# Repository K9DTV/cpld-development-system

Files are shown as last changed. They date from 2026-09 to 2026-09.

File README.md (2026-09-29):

> **Archived — final / last release.** This project is complete and frozen. Issues and PRs are not expected; the tree is the historical record.
# CPLD Development System

A hand-designed Altera MAX 7000S CPLD development board and the digital labs built on it — from Lake Washington Institute of Technology **Electronics 211** (2017–2018), by **James Burney (K9DTV)**.

This repository packs the PCB design, fabrication outputs, board photos, project write-ups, and a Quartus calculator experiment that targeted the board.

<p align="center">
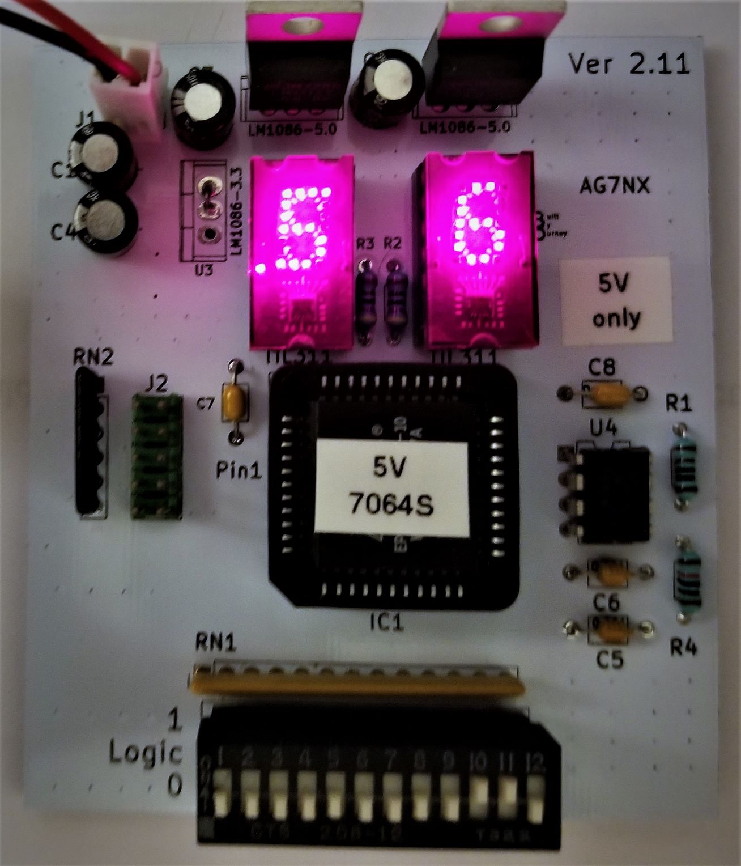
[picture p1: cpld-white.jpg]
CPLD development board (white silkscreen / Ver2)
  
  &nbsp;
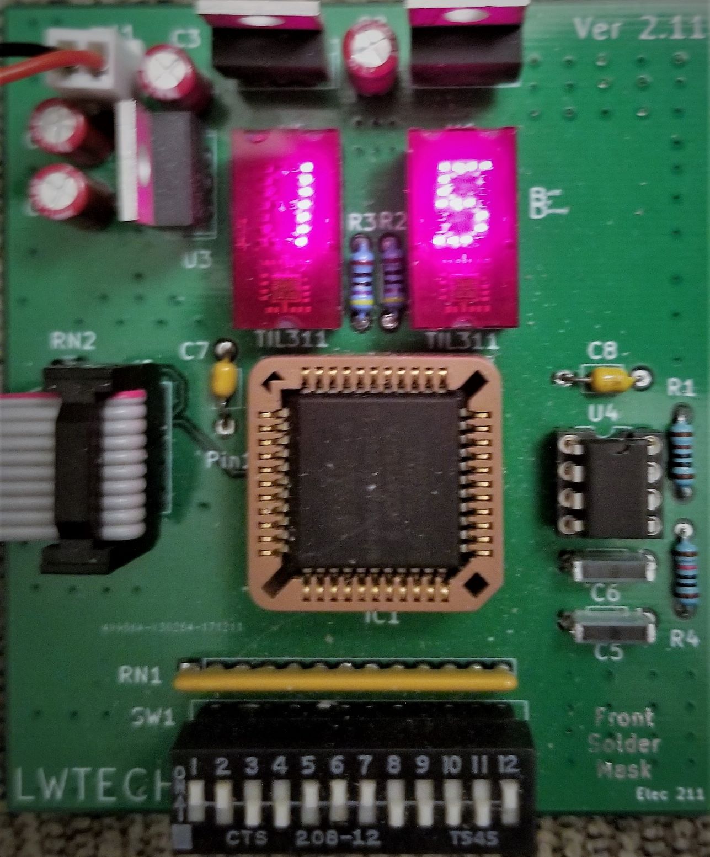
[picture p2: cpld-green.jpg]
CPLD development board (green / Ver1 style)
  
</p>

## What this board is

The goal was a durable **printed** CPLD trainer for the same class work that started on a hand-wired prototype: DIP switches in, dual hexadecimal TIL311-style displays out, on-board clock, and a standard JTAG/ByteBlaster programming header.

Two PCB revisions shipped:

| Version | How to spot it | Notes |
|---|---|---|
| **Ver1** | No silkscreen | Used for most lab examples in the docs |
| **Ver2** | Has silkscreen | Three display-control pins remapped (see pin table below) |

Power: about **6.5 V–12 V** input (prefer the low end; regulators get hot). Current-limit around **160 mA** when using a bench supply. Drive each display **decimal point with an open-drain** buffer so the DP turns fully off.

Supported CPLDs (PLCC-44):

- **EPM7032** (32 macrocells) — enough for display/switch tests  
- **EPM7064AE** (64 macrocells) — needed for the full calculator project  

The Quartus project in this repo is set for family **MAX7000S**, device **EPM7160SLI84-10** (a larger sibling used while compiling the calculator logic).

## Repository layout

```
.
├── README.md
├── cpld-white.jpg / cpld-green.jpg   # Assembled boards
├── cpld-pcb.png / cpld-sch.png       # Layout / schematic views
├── PCB-files/
│   ├── cpld/                         # KiCad schematic + PCB (legacy KiCad 4 era)
│   └── CLPD-grb/                     # Gerbers + drill for fab
├── calulator/                        # Quartus II project (filename spelling preserved)
├── project docs/                     # Word write-ups (board build, PCB, counter, finals)
└── homework/                         # Class notes (ELEC 211 Ch. 4)
```

Folder and filename spellings (`calulator`, `CLPD-grb`, spaces in `project docs`) match the original archive on purpose.

## Hardware pin map

DIP switches are active-low (closed = logic 0). Most designs invert them in the CPLD so “switch ON” reads as a 1 in the logic.

| Function | Ver1 CPLD pin | Ver2 CPLD pin |
|---|---|---|
| DIP SW 1–12 | 4, 5, 6, 8, 9, 12, 11, 14, 16, 17, 19, 18 | same |
| Clock (~66.6 kHz from 555) | 24 | 24 |
| Display A / B / C / D | 27 / 25 / 26 / 28 | same |
| Display Blank | 29 | 29 |
| Right Latch | **31** | **33** |
| Left Latch | **33** | **36** |
| Right DP | 34 | 34 |
| Left DP | **36** | **31** |

Programming-header pins follow the usual Altera JTAG layout (not duplicated in the table).

### Major bill of materials (either revision)

| Ref | Part | Notes |
|-----|---|---|
| IC1 | EPM7032 or EPM7064AE, PLCC-44 | 64 MC for full calculator |
| U1–U2 | LM1117-5.0 | 5 V rails |
| U3 | LM1117-3.3 | CPLD I/O / core as wired |
| U4 | LM555 | ~66.6 kHz board clock |
| U5–U6 | TIL311 (or DIS1417) | Hex displays (hard to source; eBay) |
| SW1 | 12-position DIP slide | Active-low inputs |
| RN1 / RN2 | 10 kΩ SIP arrays | Pull-ups |
| J2 | 2×5 header | Programming |

Full Digi-Key / Mouser part numbers are in `project docs/pcb document and cpld project.docx`.

## Labs and example designs

Documented in `project docs/`:

1. **Board bring-up** — display blank/latch behavior, 555 clock divider blinking both DPs (~1 Hz after ÷65536).  
2. **Priority encoder** — exercises all DIP switches into the hex displays (BCD).  
3. **Calculator** (needs **64 MC** device) — mode select on SW11/SW12:
   - SW11=0, SW12=0 → **min/max** (7485-style compare; DPs show a swap)
   - SW11=0, SW12=1 → **add**
   - SW11=1, SW12=1 → **subtract** (borrow aware)
   - SW11=1, SW12=0 → **multiply**
4. **Two-digit counter** — final-style exercise on the same pinout (`two digit counter cpld project.docx`).
5. **Hand-wired prototype** — earlier 7000-series socket board used for Ch. 4 / Ch. 7 (`211 build board.docx`).

## Quartus project (`calulator/`)

Intel/Altera **Quartus II** project created around March 2018 (Lite / Web edition era). Top entity name: `calulator`.

Block diagrams referenced by the `.qsf` (add/sub, multiplier, min/max, muxes, hex display) originally lived beside the project on the author’s desktop. Those `.bdf` sources are **not** all present in this archive — only the Quartus project shell, `db/`, and `output_files/` reports are. A recent map attempt fails because those schematic sources are missing; treat this folder as historical project metadata unless you restore the BDFs.

Suggested tools: **Quartus II 13.0 SP1** (or the 17.1 Lite build noted in the `.qsf` header) with a USB-Blaster.

## KiCad / fabrication (`PCB-files/`)

- `PCB-files/cpld/` — schematic (`.sch`), board (`.kicad_pcb`), netlist, project (KiCad 4-style `.pro`).  
- `PCB-files/CLPD-grb/` — Gerber layers (F/B Cu, mask, silk, edge cuts) and `cpld.drl`.

Open with a modern KiCad via the legacy importer, or send the Gerbers straight to a fab.

<p align="center">
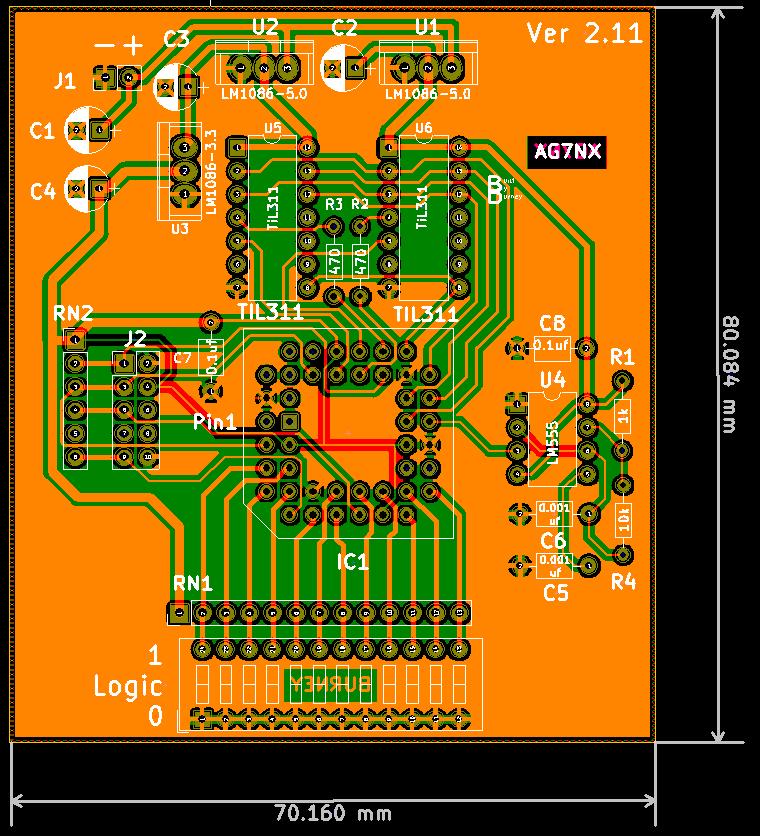
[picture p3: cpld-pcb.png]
PCB copper / X-ray style view
  
  &nbsp;
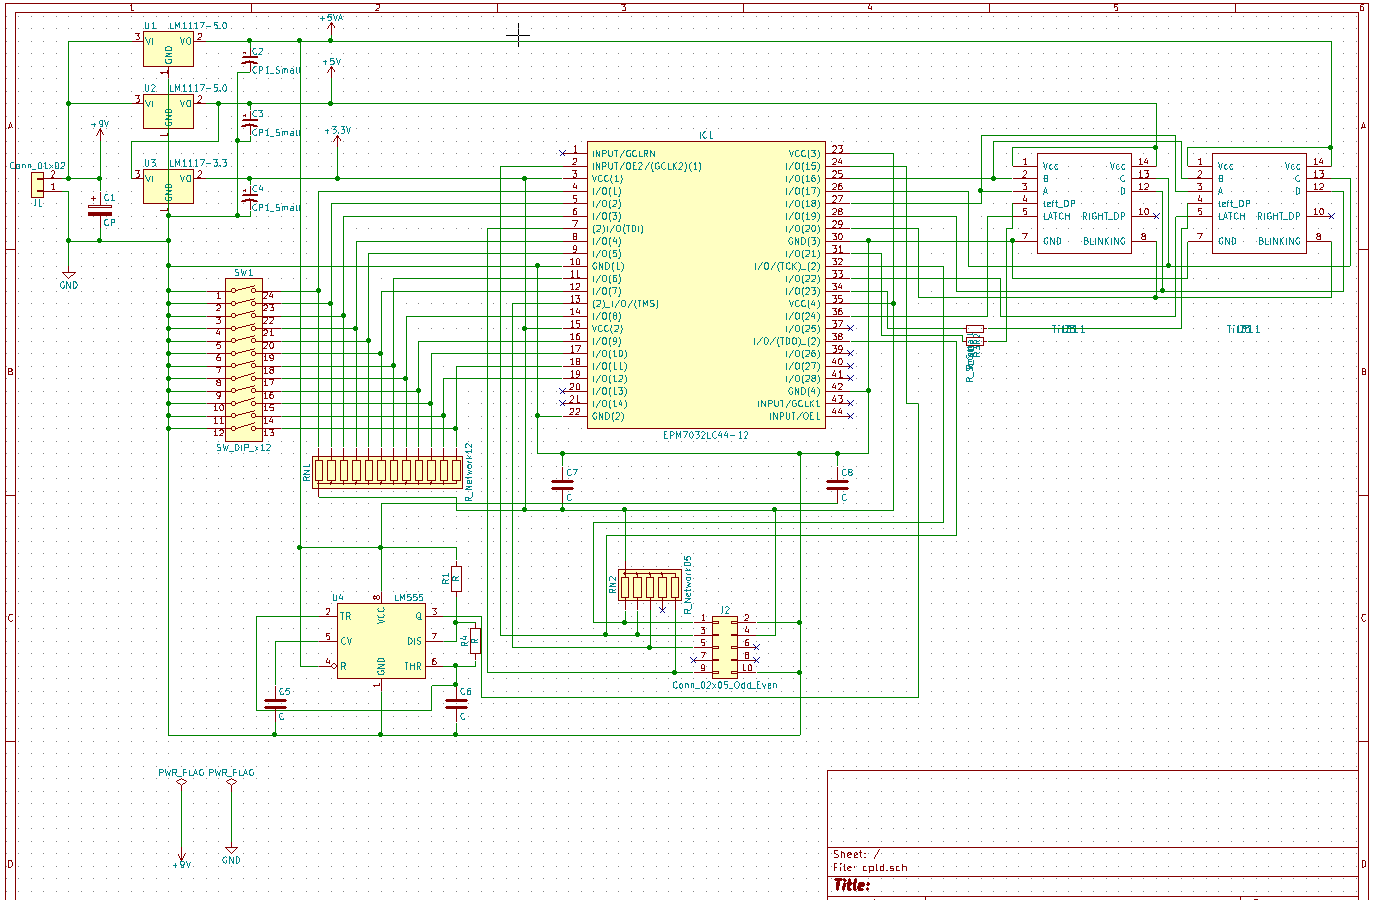
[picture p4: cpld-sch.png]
Board schematic excerpt
  
</p>

## Documentation (`project docs/`)

| File | Contents |
|---|---|
| `211 build board.docx` | Hand-wired prototype + Ch. 7 calculator path |
| `pcb document and cpld project.docx` | Ver1/Ver2 PCB, pin map, BOM, calculator labs |
| `two digit counter cpld project.docx` | Counter lab on the PCB |
| `211 PROJECT.docx` / `211 final.docx` | Course project / final write-ups |

Course context: **Lake Washington Institute of Technology**, Electronics 211, instructor **Professor Peter Welty**.

## License / provenance

MIT -- see [LICENSE](LICENSE). Personal educational hardware and reports by James Burney (K9DTV). Course homework notes in `homework/` are included as archived class material. Altera/Intel tool output remains under their respective license terms.

Site / contact: [k9dtv.com](https://k9dtv.com) · GitHub: [K9DTV](https://github.com/K9DTV)

---

*Archived from the original CPLD development-system materials (2017–2018) and published as a public K9DTV project.*

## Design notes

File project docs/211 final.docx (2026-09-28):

Lake Washington Institute of Technology

Electronics 211

Final

Priority encoder / Full Adder / Subtraction

Feb 20^t^h, 2017

James Burney

Electronics 211, Final – James Burney, Feb 20^t^h, 2017

Executive Summary – The goal the final was to use the development board that was made for chap7, and make a calculator that was a full-adder, it needed to be able to add two hexadecimal numbers. In this report, I will discuss everything I did done with this board and how I did them, and what was learned. So, in the end, the goals of the final was completed by following the fine directions of our instructor, Professor Peter Welty.

Parts used

7000ae CPLD

FDN 367 display

44 Pin PLCC Socket

10 10KOhm ¼W 5%

8 270 Ohm ¼W 5%

10 pos sw.

LM 1117 3.3

32Ga wire

Equipment used

HP 34401a

Windows 10 pc with usb blaster

I first had to use the schematic of what was done with the pin assignment of the 7000 CPLD. This was used in the end programming of the CPLD to match my assignments.

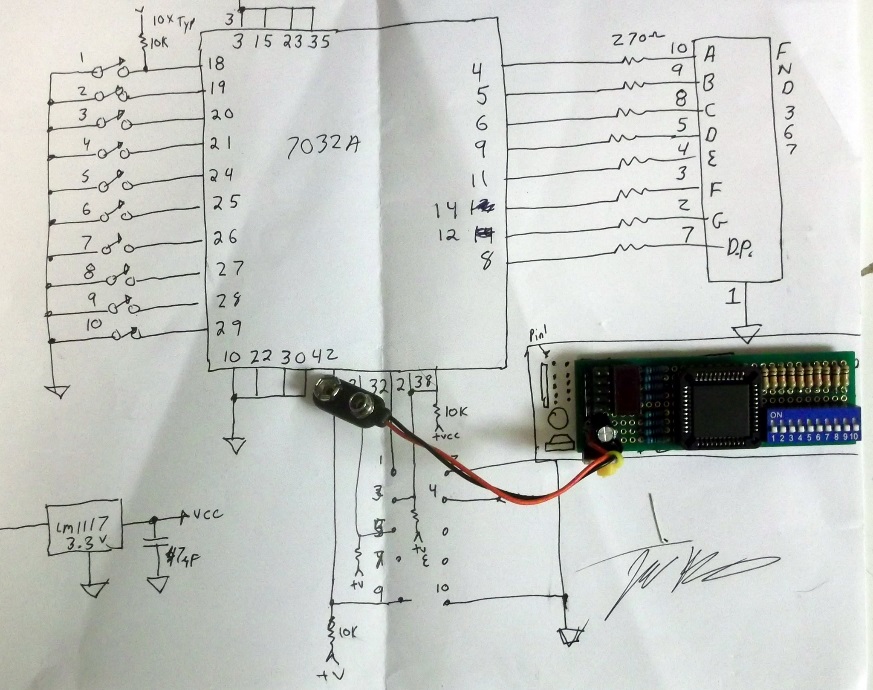
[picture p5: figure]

Electronics 211, Final – James Burney, Feb 20^t^h, 2017

After building the board, I wanted a simple way to test that all of the I/O of my layout, and test all parts of the board. To this end, I used a priority encoder to read the switch inputs from 1 to 9 and feed them into a 74147, the output was feed into a 7447 to convent the BCD to 7 segment display. The 10th switch was feed to the displays D.P. to show it operation. Some mods were made to the 74147 for negative logic levels in my design, this will be discussed later in the report.

Priority Encoder (10 to 4 Encoder) BCD Display Driver

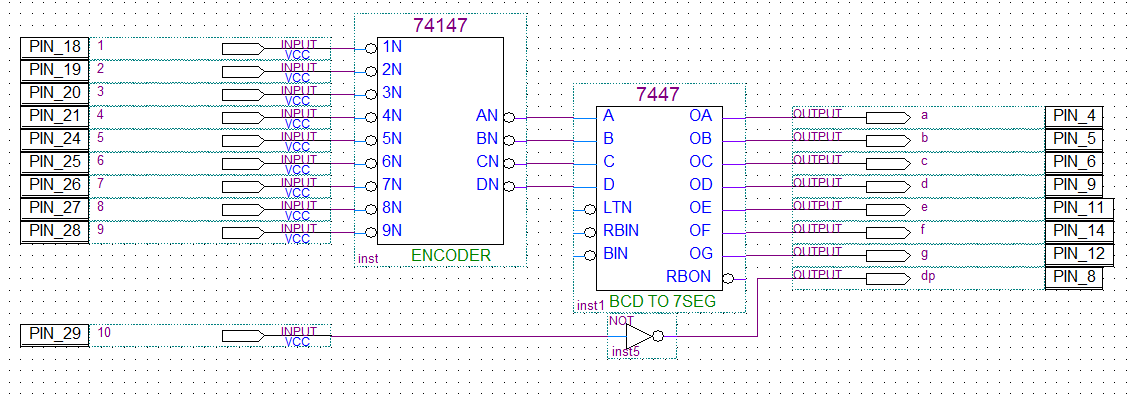
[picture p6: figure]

Next part of this lab was to build a Full adder with carry and a Hex to 7 segment display driver. This adder seemed straight forward, however, I was unable to find a hex display driver in the Max catalog of parts.

I decided to make my own and thought about it and came up with three ways to do it, mod a 7447, use a LUT, or, make a decoder and encoder, I chose the latter. First, I stared with a 4 to 16 decoder, or in other words a Binary to decimal converter. Knowing that I only had four inputs in, I knew I could use the invert and non-inverted inputs to drive 4 input gates and decode any binary number from 0x0 to 0xF. I setup 8 columns made of 1248 and not 1248, this feed 16 quad AND gates. Each gate hooked to the right code for the corresponding output. My inputs to this part of the decoder is negative logic as a switch closure is low for an on state. If one wanted to convert to positive logic, all that’s needs to be done is add four inverters in-line with the ABCD inputs. AND gates were used to decode the negative logic to convert it to decimal.

Next step was to encode this decimal number to a 7-segment display, again I thought about this and decided

It would be best to apply negative logic here to simplify the encoding. The reasoning here is that the number with the most segments on is the number eight with all 7 segments on, followed by 6 with 6 segments on. If I use negative logic, no gates will be used to decode 8, this leaves a maximum gate size needed at 6 inputs, furthermore, I only have to wire the segments to the gates that I want to be off, hence, negative logic.

Again, I setup 15 columns, as number 8 was not needed, I laid down (7) 6-input NOR gate (change to OR for CA display), one gate for each segment of the display. I simply wired each output from the decoder to each segment gate that I did not want on, this made the right numbers show up for the decode.

Next I changed out the 6-input gates that did not use all their inputs with 4-input gates. Then I did some cleanup in wiring and compression of the layout.

Next came testing and debug, and I did make some wiring mistakes, but with some troubleshooting done in the real world, I was able to solve these errors in short order.

Electronics 211, Final – James Burney, Feb 20^t^h, 2017

Binary to 7-egment display driver

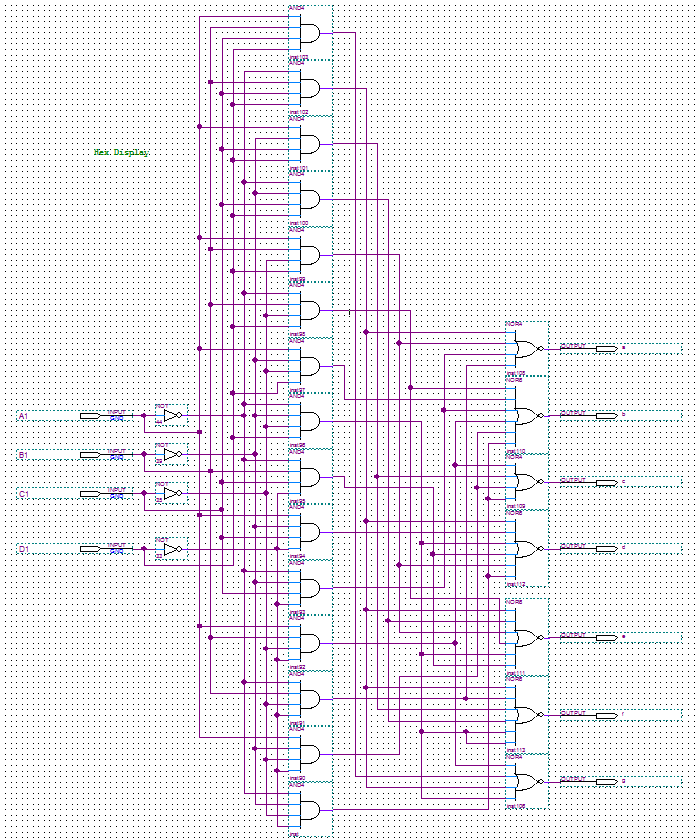
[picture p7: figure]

Although this may look hard, it is fairly straight forward and much easier to do, than to do on a breadboard.

I learned a lot from this, I learned to really think about the way I was using the gates, as resources are limited in this chip, and one wants the most bang for the buck here. I learned how to really use hierarchical deigns to simplify the work flow.

Electronics 211, Final – James Burney, Feb 20^t^h, 2017

Next up, add the full-adder, this was very easy and straightforward. I just dropped in a 7483 and bob's your uncle. So, getting no real joy from this I moved on to the extra credit stuff.

Full-Adder with carry

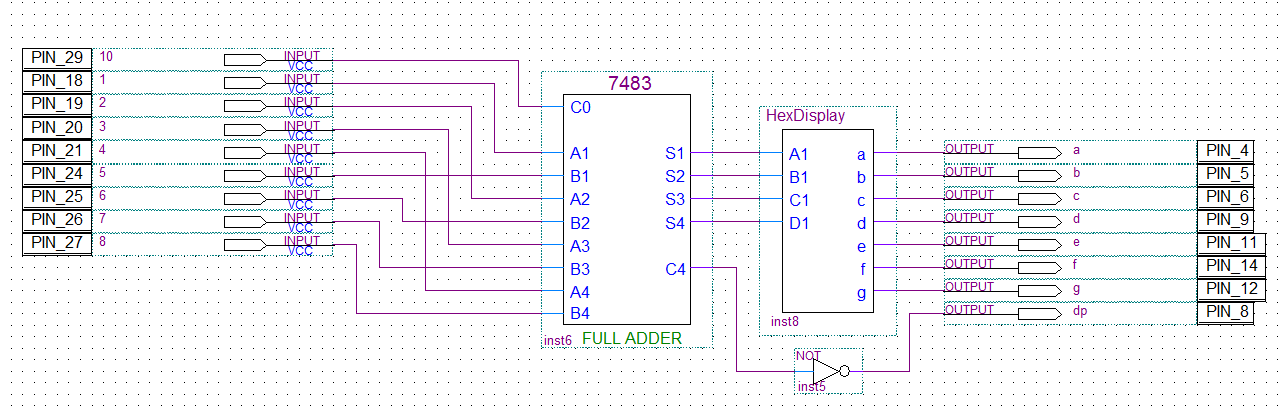
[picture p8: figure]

Next up, Full-adder with carry and subtraction with added logic for correcting DP. To add subtraction to the full-adder, all that is needed is to do a 2’s complement on the second half of the binary inputs and set the input carry to the 7483. To make it add/subtract selectable, XOR’s were used. Some added logic was also used to suppress the DP in subtraction mode.

Add/Subtract switching and DP suppression

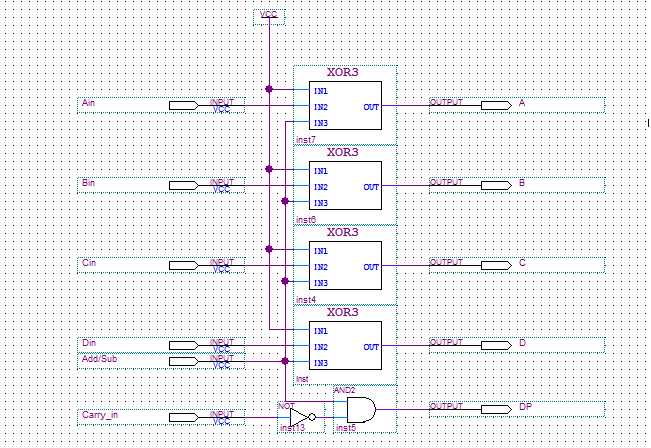
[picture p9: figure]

Full-Adder with carry / Subtraction. With D.P. suppression

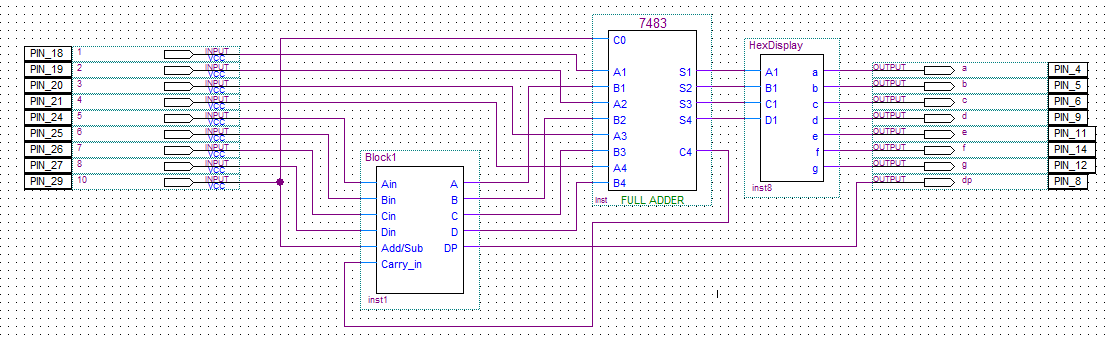
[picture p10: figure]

Electronics 211, Final – James Burney, Feb 20^t^h, 2017

Having completed the extra credit part, I still wanted to go on, so I decided that combining all this into one design, to see if I could use most of the chip, this would be great. To do this, I had to add multiplexing to the design, for inputs to the priority encoder and the adder/sub mod, and for the display.

First, I multiplexed the display converter, as seen below. This was easy as there is already a chip to do this.

All I had to do is a little layout.

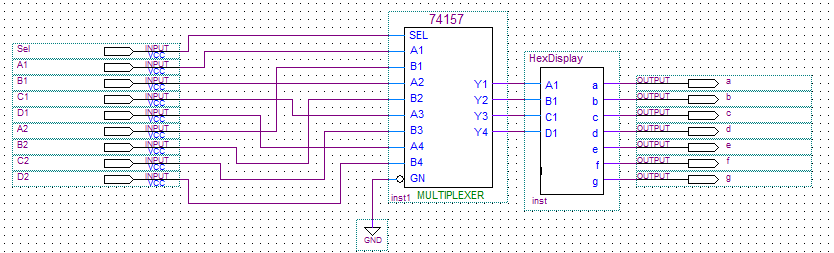
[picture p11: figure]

Next, it did come combining of the add/sub mod, as seen below. This was another easy step as I had already designed the subtraction unit with DP suppression.

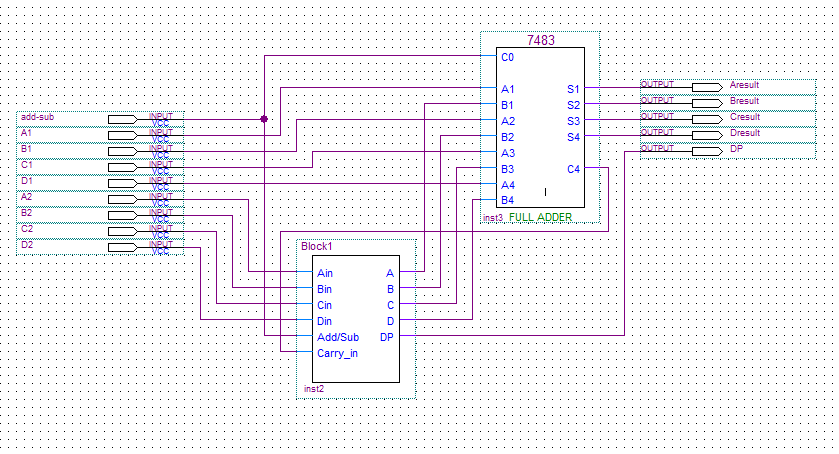
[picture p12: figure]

Electronics 211, Final – James Burney, Feb 20^t^h, 2017

Next up was to make a large 1 to 2 selector with 9 inputs and 18 outputs. This was all about layout to make the job easy. I laid out columns as before, and went ahead with wiring gates to the inputs and outputs.

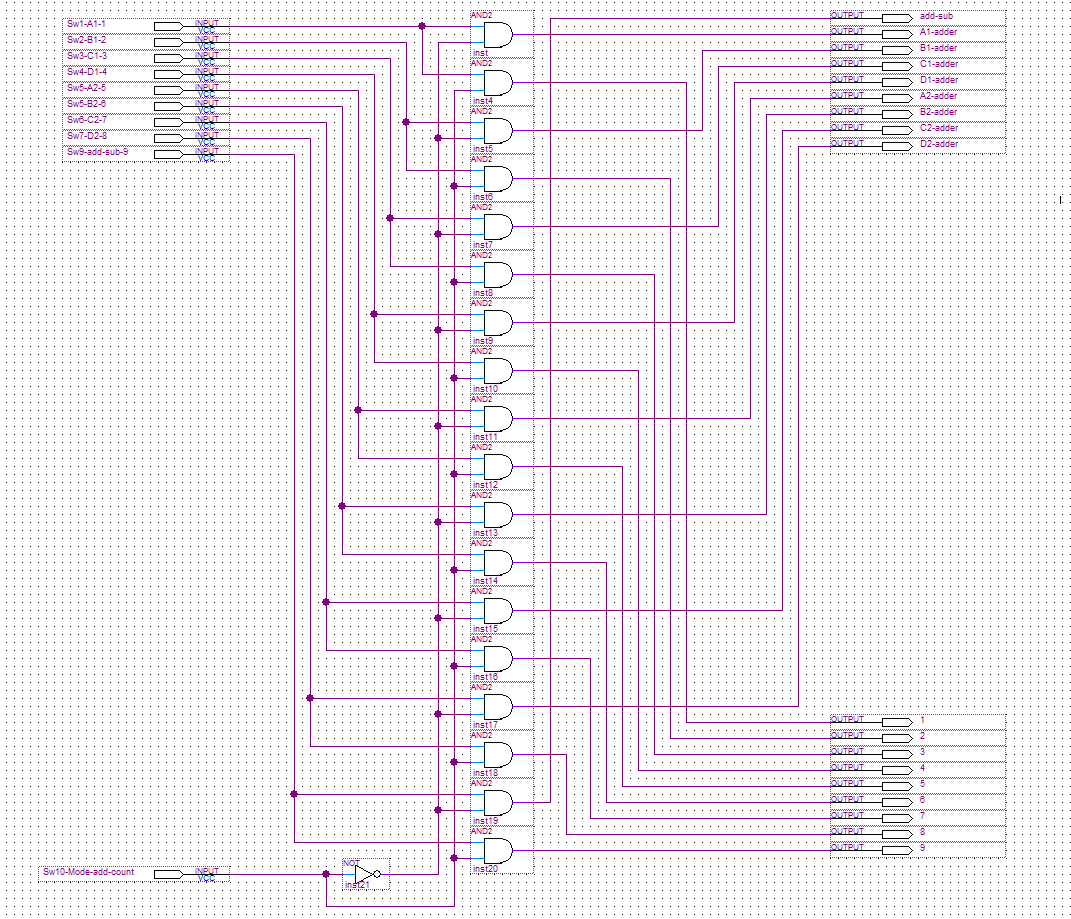
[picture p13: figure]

Next, I took all these combined sections and wired them up, as seen below.

Some changes were needed to the priority encoders first layout, as switch 10 could no longer be used just for the DP on the display, as this become the mode select switch. Switch 10 selects priority encoder when switch 10 is in the off position, and selects the adder/sub when it is on. When switch 10 is on, switch 9 becomes the add/sub selector switch, with off being add, and on being subtract.

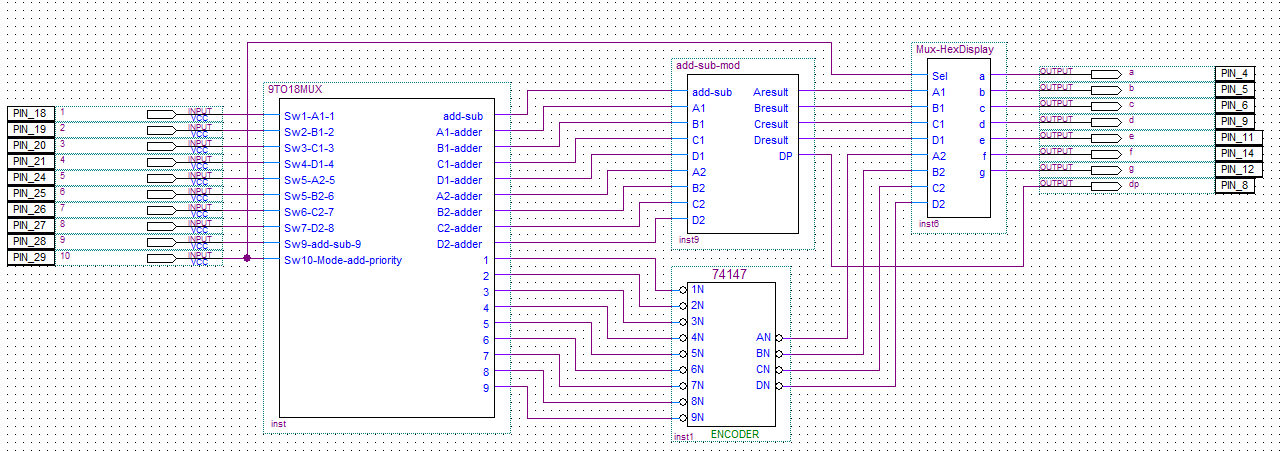
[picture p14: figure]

Electronics 211, Final – James Burney, Feb 20^t^h, 2017

Adding the priority encoder to the full adder with carry and the subtraction selector with suppression.

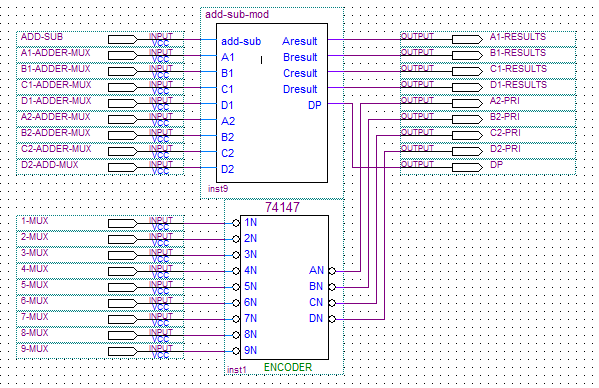
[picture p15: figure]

More hierarchical deign, however, labeling seems to take over the design.

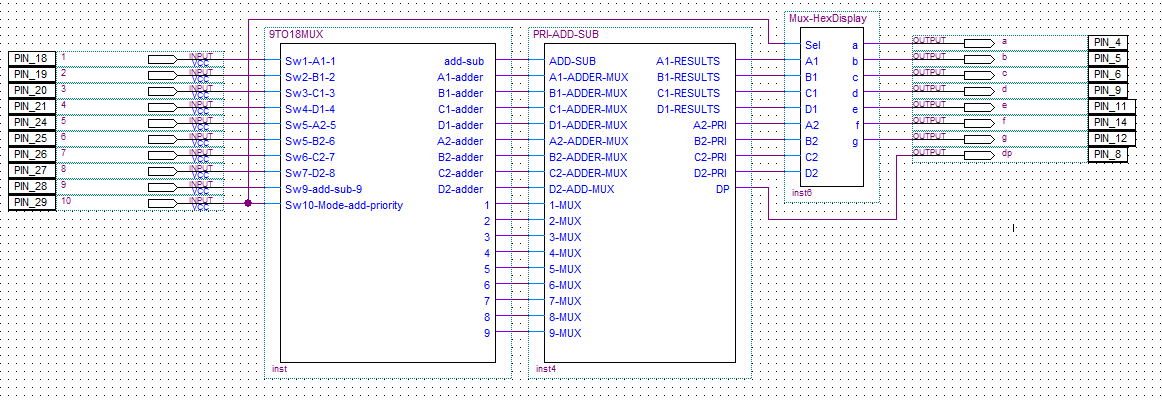
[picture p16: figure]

Next up, the ultimate reduction of this hierarchical deign, just a little too much I think.

Did not make it to my goal of 100% usage, but did make 75%

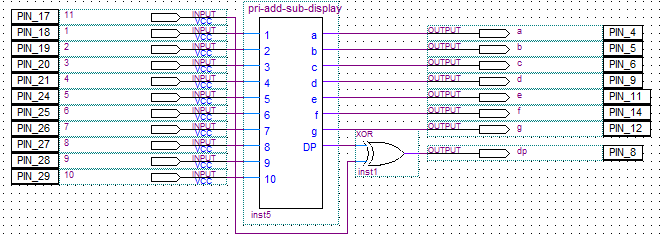
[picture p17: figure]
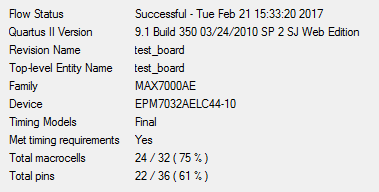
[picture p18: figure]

Electronics 211, Final – James Burney, Feb 20^t^h, 2017

Photographic documentation

Priority encoder one only

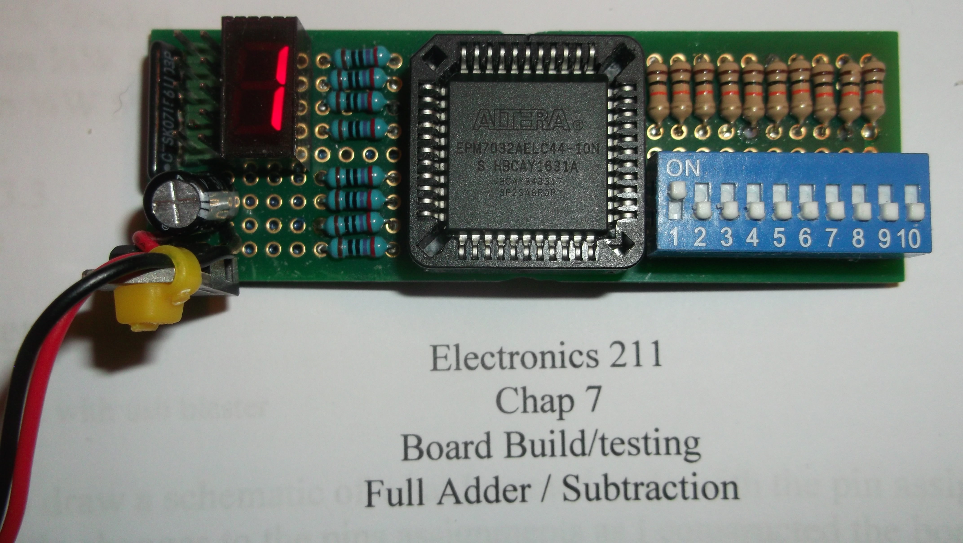
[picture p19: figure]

Priority encoder nine only

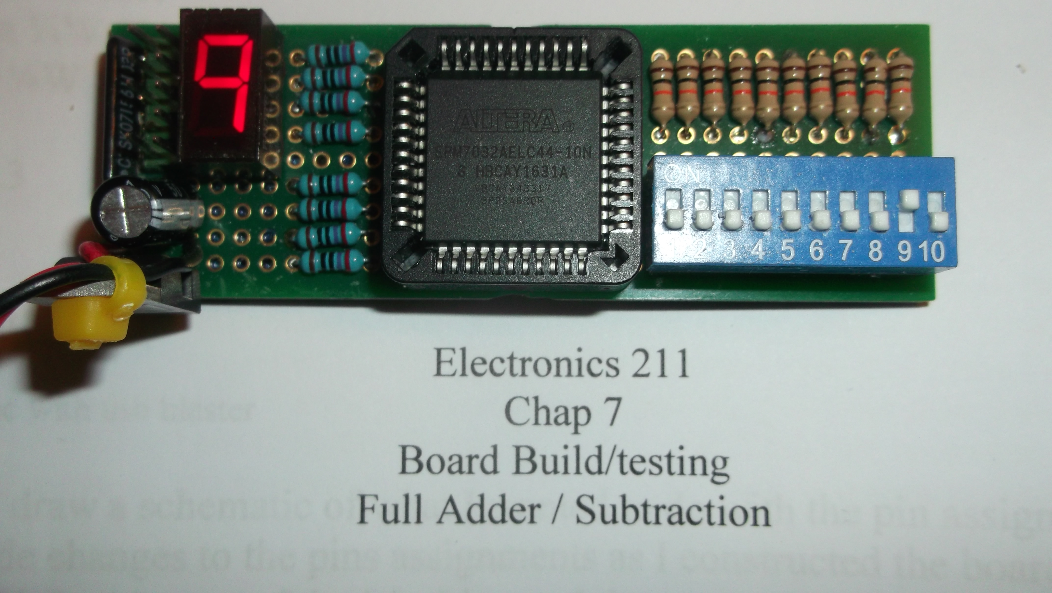
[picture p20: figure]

Priority encoder nine & 1 to 5

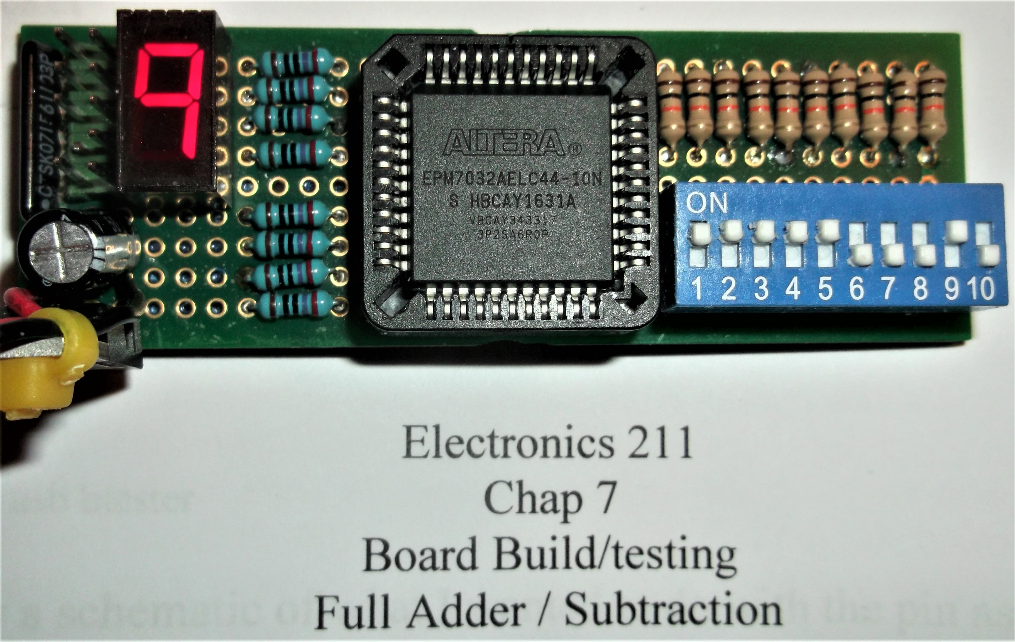
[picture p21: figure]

Electronics 211, Final – James Burney, Feb 20^t^h, 2017

Full adder with carry

0x8 + 0x2 = A or 8+2=10

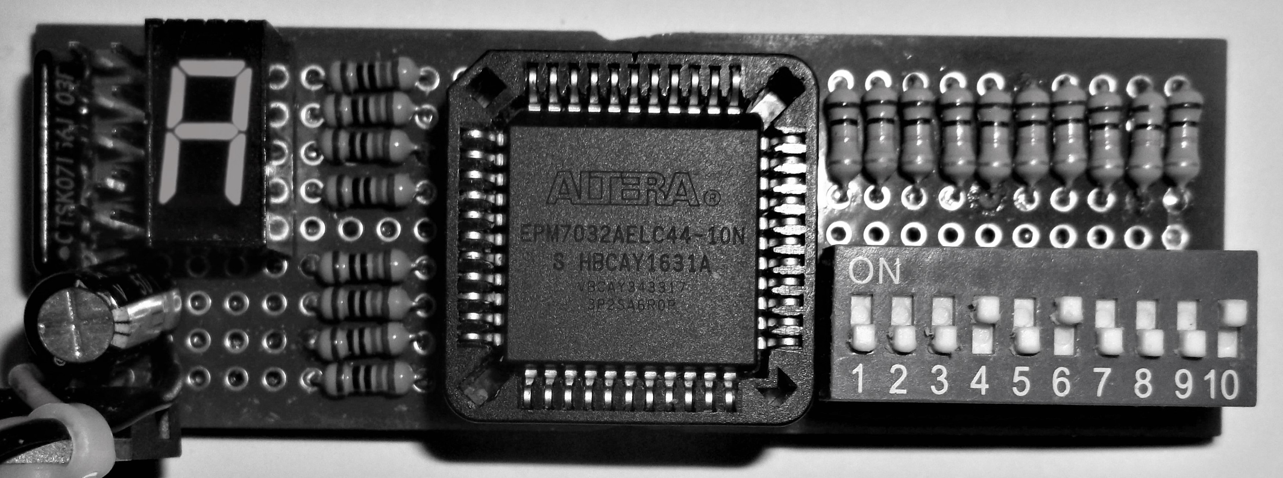
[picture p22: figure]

0x7 + 0xF = 0x16 or 7+15=22

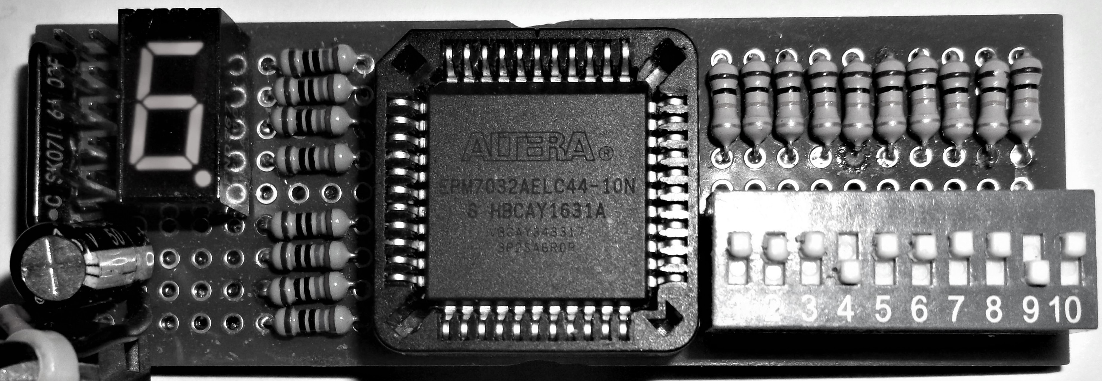
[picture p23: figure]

Subtraction

0x7 – 0x4 = 0x3 or 7-4=3

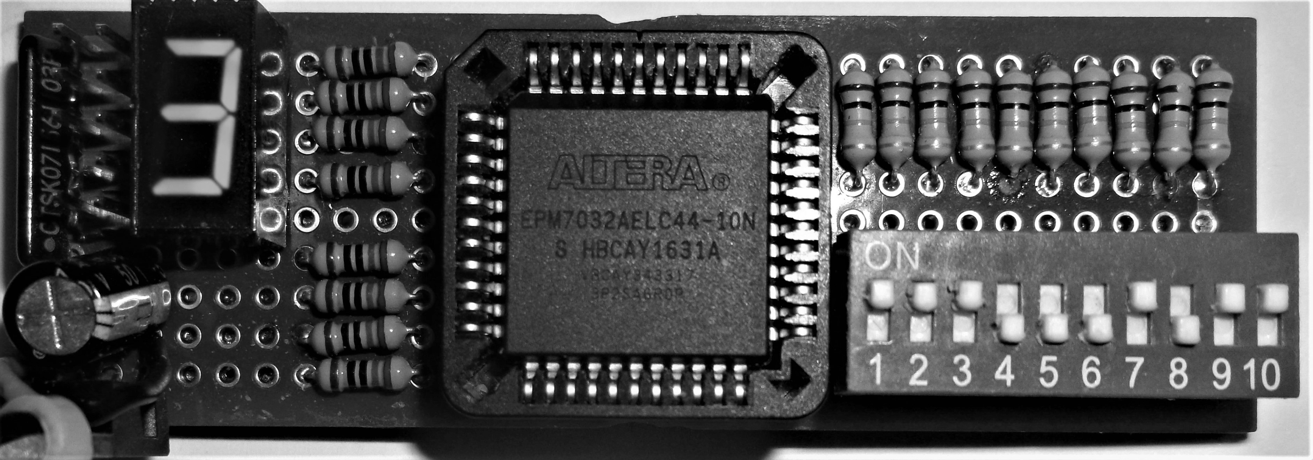
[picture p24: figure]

0x3 – 0x8 = B

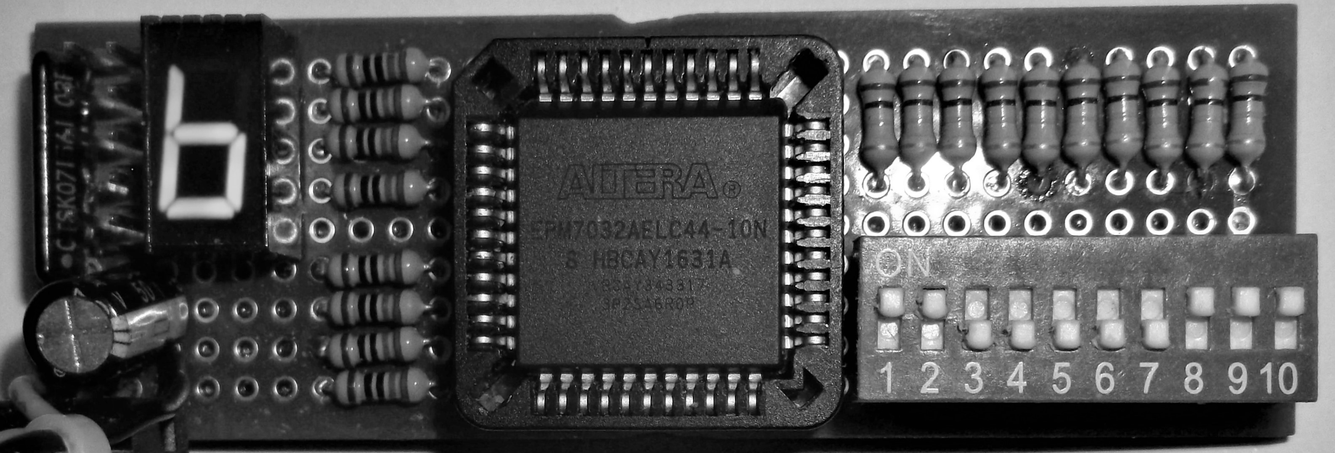
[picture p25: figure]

Electronics 211, Final – James Burney, Feb 20^t^h, 2017

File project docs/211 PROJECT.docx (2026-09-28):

Lake Washington Institute of Technology

Project CLPD Calculator

Feb 22^t^h, 2017

James Burney

Calculator Project – James Burney, Feb 22^t^h, 2017

Executive Summary – The goal the project was to use the development board to really build the calculator from the chapter 7 of the elec 211 book. First a lager chip needed to be ordered, as the design would not fit on a 32-cell unit, so a 64-cell chip was used.

Then there are some problems with the design presented in the book, along with some short cuts taken that do not take advantage of the fact a CLPD is being used in the first place.

In this report, all the steps to make this calculator will be covered mainly from a Negative logic point of view, as this is what most building this will use. Also, covered will be displaying results, and borrowing when subtracting.

Parts used

EPM7064AELC44-10 CLPD

FDN 367 display

44 Pin PLCC Socket

16 10KOhm ¼W 5%

8 270 Ohm ¼W 5%

12 position switch.

LM 1117 3.3v

32Ga. wire

First off, lets cover that this design is based on negative logic, as the input switches when on, zero volts is used to represent a logical 1, and to turn an LED on, zero volts is used to represents a logical 1. The book uses positive logic and in most cases it is a simple matter of just inverting the inputs, and the output, but not in all cases.


Calculator Project – James Burney, Feb 22th, 2017

Now to take a look at a schematic of the development board, this is not a complete schematic, as one will make their own choices as they build their unit.

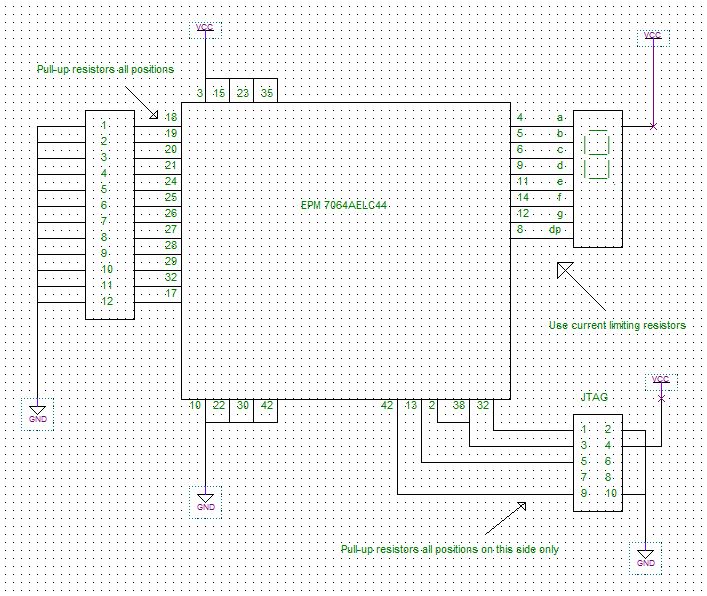
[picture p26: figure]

It should be noted imminently, that current limiting resistors, and pull-up resistors are not shown, but are needed. A minimum of a 11-position switch, and at least one 7-segment display is needed.

Note here that all parts are from a bottom view, and the regulator is a LM1117 3,3v type. Be sure to make sure the regulator you use is the same pinout.

Calculator Project – James Burney, Feb 22th, 2017

It is not the intent of this project to help you build your board, but help you in making the calculator in chapter 7 of the lab book, along with some improvements in layout and design.

The book starts out with an adder, then a full-adder and the adds subtraction to it. The book really did not cover a display driver, as it wanted you to use an extremal display decoder for this task, and that kind of defeats the whole reason for using the CLPD in the first place. So, I’ll start off with a display decoder, and if you don’t need to use a Hexadecimal display, just use a 7447 from the library of parts

For building the hex display, First, I stared with a 4 to 16 decoder, or in other words a Binary to decimal converter. Knowing that I only had four inputs in to decode the 16 states, I knew I could use the invert and non-inverted inputs to drive 4 input gates and decode any binary number from 0x0 to 0xF. I setup 8 columns made of 1248 and NOT 1248, this feed 16 quad AND gates. Each gate hooked to the right code for the corresponding output.

My inputs to this part of the decoder re negative logic, as a switch closure is low for an on state. If one wanted to convert to positive logic, all that’s needs to be done is add four inverters in-line with the ABCD inputs. AND gates were used to decode the negative logic to convert it to decimal.

Next step was to encode this decimal number to a 7-segment display, again I thought about this and decided

It would be best to apply negative logic here to simplify the encoding. The reasoning here is that the number with the most segments on is the number eight with all 7 segments on, followed by 6 with 6 segments on.

If I use negative logic, no gates will be used to decode 8, this leaves a maximum gate size needed at 6 inputs, furthermore, I only have to wire the segments to the gates that I want to be off, hence, negative logic.

Again, I setup 15 columns, as number 8 was not needed, I laid down (7) 6-input NOR gate (change to OR for CA display), one gate for each segment of the display. I simply wired each output from the decoder to each segment gate that I did not want on, this made the right numbers show up for the decode.

Next I changed out the 6-input gates that did not use all their inputs with 4-input gates. Then I did some cleanup in wiring and compression of the layout.

Next came testing and debug, and I did make some wiring mistakes, but with some troubleshooting done in the real world, I was able to solve these errors in short order.

Note that if you are using positive logic or a common cathode display, just add four inverters to the inputs.

If you are using both positive logic and a common cathode display, invert both inputs and outputs,

The best way to invert the outputs is too change out the NOR gates with OR gates.

Calculator Project – James Burney, Feb 22th, 2017

Binary to 7-egment display driver


Although this may look hard, it is fairly straight forward and much easier to do, than to do on a breadboard.

I learned a lot from this, I learned to really think about the way I was using the gates, as resources are limited in this chip, and one wants the most bang for the buck here. I learned how to really use hierarchical deigns to simplify the work flow.

Calculator Project – James Burney, Feb 22th, 2017

I am going to skip the adder/full-adder, and just jump in to the adder with carry and the subtraction.

The Full-adder with carry and subtraction with added logic for correcting DP. To add subtraction to the full-adder, all that is needed is to do a 2’s complement on the second half of the binary inputs and set the input carry to the 7483. To make it add/subtract selectable, XOR’s were used. Some added logic was also used to suppress the DP in subtraction mode. Again, this is for negative logic.

Add/Subtract switching and DP suppression


I used the logic below to test my ideas based on the information provided by the book. Then added to it to even add a borrowing to it when subtracting.

Full-Adder with carry / Subtraction. With D.P. suppression


Calculator Project – James Burney, Feb 22th, 2017

After getting my full adder with carry, and subtraction with borrow working, this is what it now looks like.

DE Morgan theorem was used here to figure out how to drive the display for adding and subtracting with carry and borrowing.

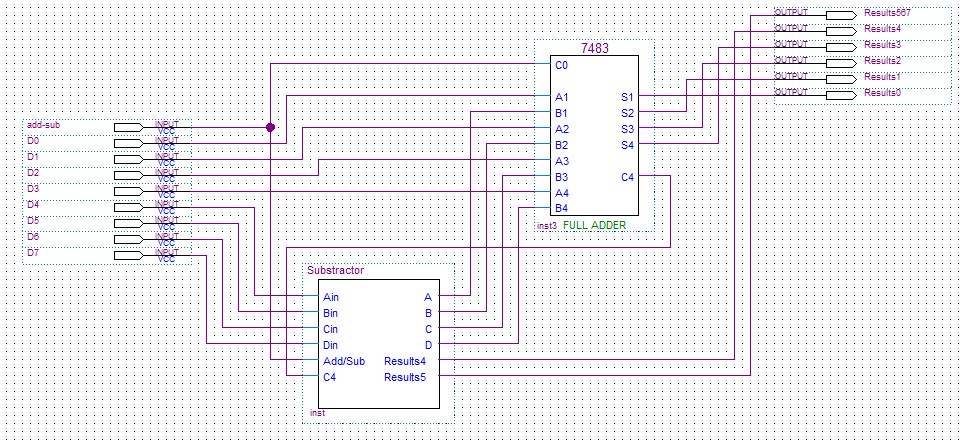
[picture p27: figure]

Here are the details of the subtraction unit with borrowing. This allows only four states on the MSD of the display. The four allowed states are F, E, 1, and 0. F and E are used in subtraction and 1, and 0 are used in addition with carry.

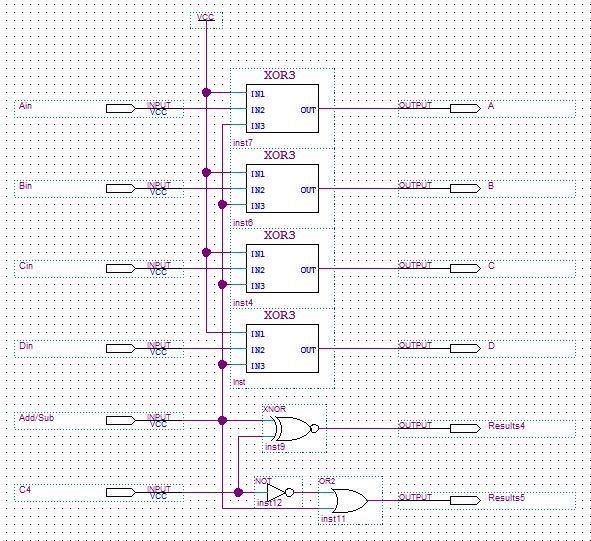
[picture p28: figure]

Calculator Project – James Burney, Feb 22th, 2017

Now would be a good time to look at the multiplier, the book does a good job of showing you the multiplier, however, really does not do a good job on its layout. Also, it was designed for positive logic.


However, as said earlier, it is easy to convert in most cases. In this case, the easiest way to do this conversion, is to simply remove the inverts on the inputs and the outputs. Care must be taken when doing this as layout as it is a little complicated.


Next in Min-Max, this is just a magnitude comparator driving two 2 to 1 multiplexers. The state of AGBO and ALBO determines what nibble will be displayed on digit. To convert to positive logic, just simply remove the inverts on the inputs and the outputs, and reverse the AGBO, and ALBO connections.

Calculator Project – James Burney, Feb 22th, 2017

Next the book made a multiplexer for the three-function calculator by using three tristate buffers.

This however is a problem, as the book did not use a display encoder internally, they could use these buffers on the output of the device. However, tristate buffers are not allowed on the internal buss of the EPM70xxA, a real multiplexer must be used. Now to do this, you could just use a 74157, but I wanted to conserve space in the CLPD, so I made my own.

The multiplexer has to select one of the three functions of the calculator. As can be seen, the decoder logic is just inverting the control signals.


Calculator Project – James Burney, Feb 22th, 2017

Now multiplexing the display, as I only used one 7-segment display, and this calculator needs two digits. This CLPD has more than enough pins to add a second display. Only 23 pins were used and this leaves 13 pins for you to add another display and even more input switches.

If you chose to add a second display, only 5 microcells are left, however, deleting the display multiplexer should make this fit. (Tried it and it will not fit)

The multiplexed the display converter, as seen below.

Next, I took all these combined sections and wired them up, as seen below.

This is where careful layout of the hierarchical deign comes in. this makes understanding the follow easy.

I really don’t think the book conveyed this very well.


The final design showing the pinout used in this design.


Calculator Project – James Burney, Feb 22th, 2017

Usage of the EPM7064AE

Photographic documentation

Note: The decimal point of the display shows what digit is being displayed. With the decimal point lit, the MSD is displayed and off is the LSD.

Full adder with carry (switch 9 is add/subtract. add is the off position)

0x1 + 0x0 = 1


0x1 + 0x8 = 9


0x9 + 0x9 = 0x12


It is easy to see in the pictures above, that the carry function works just fine.

Calculator Project – James Burney, Feb 22th, 2017

Subtraction with borrow

0x3 – 0x1 = 02 (switch 9 is add/subtract. Subtract is the on position)


0x1 – 0x9 = 0xF8


Greater than / Less than

0x3 > 0x1 = 0x31


0x2 < 0x4 0x42


Calculator Project – James Burney, Feb 22th, 2017

Multiplication

0x6 X 0x2 = 0x0C


0x7 X 0xA = 0x46


0xF X 0xF = E1


Calculator Project – James Burney, Feb 22th, 2017

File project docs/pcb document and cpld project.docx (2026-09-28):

Lake Washington Institute of Technology

7th Quarter Project

CPLD development board

January 12, 2018

Jim Burney

7th Quarter Project - CPLD development board CPLD - Jim Burney – January, 2018

Executive Summary – The goal of this project was to make a very high quality Printed Circuit board for making things like the calculator from the Digital Electronics Class 211. Using

This project documents the two revisions of the boards made, and some examples what can be done with them. This project took over 33 hours for the development of the documentation, and the development of the projects to make with it. What follows is the documentation of the two versions. Even though the two only have three pins from the CPLD to the display changed, this needs to be shown.


Ver1


Ver2

7th Quarter Project - CPLD development board CPLD - Jim Burney – January, 2018

The easiest way to tell the two versions apart is simple, version 1 has no silkscreen, and version 2 does. There are also other minor changes in the layout, to make the board better.

What follows is the pin assignments used for the two boards, this is really all that matters for their use.

Component Version1 Version2

CPLD Pin CPLD Pin

Dip switch 1 4 4

Dip switch 2 5 5

Dip switch 3 6 6

Dip switch 4 8 8

Dip switch 5 9 9

Dip switch 6 12 12

Dip switch 7 11 11

Dip switch 8 14 14

Dip switch 9 16 16

Dip switch 10 17 17

Dip switch 11 19 19

Dip switch 12 18 18

Clock 66.6KHz 24 24

Display

Right/left A 27 27

Right/left B 25 25

Right/left C 26 26

Right/left D 28 28

Right/left Blank 29 29

Right Latch 31 33 *

Left Latch 33 36 *

Right DP 34 34

Left DP 36 31 *

*Changes made from version 1 to version 2

Ver1 is used for all examples used in this report.

Note: The pins to the programming header are not shown as they are standard.

some notes on the use of this board, always drive the Decimal Point of the display with and Open Drain buffer. If you don’t, the DP may not turn fully off completely, depending on the voltage supplied. The supply voltage should be from 6.5 Volts to 12 Volts, and current should be limited to about 160mA. Iif using a power supply, please current limit. The regulators will get very HOT, so it is better to operate on the lowest voltage possible. At 9V input, power dissipation is 3/4Watts in the 5V regulators.

7th Quarter Project – CPLD development board CPLD – Jim Burney – January, 2018

The following is the parts list for either version of this board.

R1 1K ¼ WATT 1% RNF14FTD1K00CT-ND

R2-R3 470 Ohms ¼ WATT 1% RNF14FTD470RCT-ND

R4 10k ¼ WATT 1% RNF14FTD10K0CT-ND

RN1 ARRAY 12 RES 10K 13Sip 4613X-101-103LF-ND

RN2 ARRAY 5 RES 10K 6Sip CSC10KE-ND

C1-C4 22uF 16v 710-860020372002 Mouser

C5-C6 1000pF 495-6839-ND

C7-C8 .1uF 478-5194-ND

IC1 CPLD 32MC 10NS PLCC 544-1995-ND

*Or CPLD 64MC 10NS PLCC 989-EPM7064AELC44-10 Mouser

U1-U2 LM1117-5.0 LM1117T-5.0/NOPB-ND

U3 LM1117-3.3 (https://www.digikey.com/product-detail/en/texas-instruments/LM1117T-5.0-NOPB/LM1117T-5.0-NOPB-ND/363594)LM1117T-3.3/NOPB-ND

U4 LM555 LM555CNFS-ND

U5-U6 Til311 HARD TO FIND (See note) eBay / Jim Burney

SW1 SLIDE DIP 12-POS CT20812-ND

J1 1x2 Header 2.54mm WM18785-ND

J2 2x5 Header 2.54mm 437-8021001010002101 Mouser

PCB Custom Board JHB00005 Jim Burney

Sockets for board

PLCC44 AE10057-ND

**DIP-24 Pin 575-1104732441001000 Mouser

**DIP-14 Pin (2 needed) 575-1104731441001000 Mouser

**DIP-8 Pin 575-1104730841001000 Mouser

**Adhesive feet (4 needed) RM822-ND

*needed if you want to do all projects

**Optional parts.

All parts are from Digi-key unless otherwise noted.

NOTE: The Til311 can be found on eBay also, the DIS1417 may be able to replace the Til311.

By the time you are done, the cost will be about $100 for each assembled board, if done in quantity of ten. Your mileage may vary, as mine was much higher, as three different boards were made and each set of 10 cost about $40.

7th Quarter Project – CPLD development board CPLD – Jim Burney – January, 2018

Ver1


Ver2


Note: Pin 1of RN1 is on the right side for version 1, and on the left side for version 2.

7th Quarter Project – CPLD development board CPLD – Jim Burney – January, 2018

The first project was done to test the displays, and the clock on the board, this is really a simple test. Switch 1 is the A bit, and 2 is B, 3 is C, and 4 is D. Switch 9 is the Latch to the Left display, and 10 is Latch to the right display. Finally switch 12 controls the blanking of the displays.

Negative logic comes from the switches, as they provide a low (0) when the switch is on, so all switches used are inverted, so that when the switch is on, it makes this a high (1).

Ver1 is used for all examples used in this report.

This takes the negative logic from the switches and converts it to positive logic for the display.

By doing this, it makes it easier to understand how the hexadecimal displays work.

First you can see that as long as switch 12 is low, the data on the displays can be seen, but as soon as you turn the switch on, the display BLANKS. This shows that the blank signal to the display is active high. The data bits are really straight forward, but the bits go to both displays, so the Latch signal is used to hold the data on each display. If you have switch 9 off and stich 10 on, as you change the positions of switches 1 to 4, you will see that only the left display changes and the right display hold whatever was on the display when you started. This right display has Latched the data, as the Latch signal is active high, this is an easy way to do multiplexing to reduce the number of wires in a system.

So, let’s take a look at the flashing DP of the displays. The CPLD is clocked by an evil 66.6Khz signal form a 555 timer IC and is connected to pin 24 of the CPLD. A divider chain divides this by 65,536, giving about a 1Hz signal, this in turn is connected to one of the displays DP, then the signal is inverted and drives the others displays DP.


Ver1 is used for all examples used in this report.

This is simply a chain of four divide by sixteen counters that drive the displays DP.

This test also let you know how to drive the displays, and that the clock source workes. however, it did not test the switches. This is addressed in the next project with a priority encoder to test the switches and display.

7th Quarter Project - CPLD development board PLD - Jim Burney – January, 2018

A priority encoder takes the highest decimal numbered input and converts that to BCD, regardless of any lower numbered inputs. This encoder is based on negative logic (active low, or NOT by a bar over the signal name) so the switch inputs don’t need to be inverted, as they are negative logic as well. The output however needs to be inverted as the displays work on positive logic (active high). This project shows that all the switches are working, as well as the displays.


Ver1 is used for all examples used in this report.

Again, the counter chain is used to toggle the DP of the displays and show that the 555 timer is working at the right frequency, and clocking the CPLD.

Ver1 is used for all examples used in this report.

Below is a table entered for this encoder


Ver1 is used for all examples used in this report.

7th Quarter Project - CPLD development board CPLD - Jim Burney – January, 2018

In this last project you will make a calculator that can add/subtract, multiply, and show min/max number. It should be noted that you need the 64 MC chip to do this project.

Min-Max Module


This section is right out of the textbook with a few minor changes to work right, and the control of the display DP. The 7485 is a four-bit magnitude comparator and has outputs to tell what four-bit bank is higher than the other. This output drives the two multiplexers that can swap the two four-bit digits based on this comparison. When the second four-bit number is grater then the first four-bit number, the displays DP will come on and the four-bit numbers will be swapped. The DP will only light-up in this mode.

The dip switch is setup as follows

With Switch 12 and switch 11 both off, the calculator is in min max mode.

Switch 1 to 3 are the first nibble, and switches 4 to 8 are the second nibble. So, if

1011 0110 is entered on the switches, then D6 will be displayed. However, if the numbers are

Reversed 0110 1011 then D6 will be displayed and both DP will be turned on, this shows that the numbers were swapped.

7th Quarter Project - CPLD development board CPLD - Jim Burney – January, 2018

The next part of the calculator is the adder/subtractor module, this is very modified from the book to correct for a borrow when subtracting. The full adder has a carry output and this is used when adding.


This subtractor module is also from the book and modified, this allows a borrow to happen if the second number is larger than the first number.


With Switch 11 off and switch 12 on, the calculator is in addition mode.

If 1110 1001 00 01 is put on the dip switch, this is 0xEh + 0x9h and add mode.

The results should be 0x17h, go ahead and try 0111 1011 00 01. 0x7h + 0xB.

The results should be 0x12h.

With Switch 11 on and switch 12 on, the calculator is in subtraction mode.

Enter 1110 1001 00 11 on the dip switch, this is 0xEh – 0x9h and subtract mode.

The results should be 0x5h.

Enter 0110 1101 00 11 is put on the dip switch, this is 0x6h – 0xDh and subtract mode.

The results should be 0xF9h, as a barrow occurred.

7th Quarter Project - CPLD development board CPLD - Jim Burney – January, 2018

Next is the multiplier module


This is right out of the text book, again done slightly differently to make it easier to use.

The multiplication module is selected by switch 11 being on and switch 12 being off.

Enter 1110 1001 00 11 on the dip switch, this is 0xEh x 0x9h and subtract mode.

The results should be 0x7Eh.

Enter 0110 1101 00 11 is put on the dip switch, this is 0x6h x 0xDh and subtract mode.

The results should be 0x4Eh, as a barrow occurred.

Enter 1110 1100 00 11 is put on the dip switch, this is 0xEh x 0xCh and subtract mode.

The results should be 0xA8h, as a barrow occurred.

Enter 1111 1111 00 11 is put on the dip switch, this is 0xFh x 0xFh and subtract mode.

The results should be 0xE1h, as a barrow occurred.

Enter 1000 0010 00 11 is put on the dip switch, this is 0x8h x 0x4h and subtract mode.

The results should be 0x10h, as a barrow occurred.

Enter 1000 0100 00 11 is put on the dip switch, this is 0x8h x 0x4h and subtract mode.

The results should be 0x20h, as a barrow occurred.

Enter 1000 1000 00 11 is put on the dip switch, this is 0x8h x 0x8h and subtract mode.

The results should be 0x40h, as a barrow occurred.

7th Quarter Project - CPLD development board CPLD - Jim Burney – January, 2018


This is an over view of all the modules that make up the calculator’s functions. Some of the modules you have already seen. The two sections left are both multiplexers, one selects what function module to use, and the other multiplexes the data from eight-bits to four-bit for the display buss.


7th Quarter Project - CPLD development board CPLD - Jim Burney – January, 2018

Display multiplexer module


Module to pinout module


Ver1 is used for all examples used in this report.

Pinout table


Ver1 is used for all examples used in this report.

7th Quarter Project - CPLD development board CPLD - Jim Burney – January, 2018

X-ray view of back layer of Version 2 board


7th Quarter Project - CPLD development board CPLD - Jim Burney – January, 2018

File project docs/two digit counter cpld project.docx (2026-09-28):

Lake Washington Institute of Technology

CPLD development board

Two Digit Counter

May 27, 2018

Jim Burney

CPLD development board - Two Digit counter - Jim Burney – May 27, 2018

What follows is the documentation of the CPLD development board being used to make a

Two Digit Calculator for your final.


This is the schematic of the board.

The pin assignments used for the board.

Component CPLD Pin

Dip switch 1 4

Dip switch 2 5

Dip switch 3 6

Dip switch 4 8

Dip switch 5 9

Dip switch 6 12

Dip switch 7 11

Dip switch 8 14

Dip switch 9 16

Dip switch 10 17

Dip switch 11 19

Dip switch 12 18

Clock 66.6KHz 24

Display

Right/left A 27

Right/left B 25

Right/left C 26

Right/left D 28

Right/left Blank 29

Right Latch 33

Left Latch 36

Right DP 34

Left DP 31

Note: The pins to the programming header are not shown as they are standard.

CPLD development board - Two Digit counter - Jim Burney – May 27, 2018

The following is the parts list for the board.

R1 1K ¼ WATT 1% RNF14FTD1K00CT-ND

R2-R3 470 Ohms ¼ WATT 1% RNF14FTD470RCT-ND

R4 10k ¼ WATT 1% RNF14FTD10K0CT-ND

RN1 ARRAY 12 RES 10K 13Sip 4613X-101-103LF-ND

RN2 ARRAY 5 RES 10K 6Sip CSC10KE-ND

C1-C4 22uF 16v 710-860020372002 Mouser

C5-C6 1000pF 495-6839-ND

C7-C8 .1uF 478-5194-ND

IC1 CPLD 32MC 10NS PLCC 544-1995-ND

*Or CPLD 64MC 10NS PLCC 989-EPM7064AELC44-10 Mouser

U1-U2 LM1117-5.0 LM1117T-5.0/NOPB-ND

U3 LM1117-3.3 (https://www.digikey.com/product-detail/en/texas-instruments/LM1117T-5.0-NOPB/LM1117T-5.0-NOPB-ND/363594)LM1117T-3.3/NOPB-ND

U4 LM555 LM555CNFS-ND

U5-U6 Til311 HARD TO FIND (See note) eBay / Jim Burney

SW1 SLIDE DIP 12-POS CT20812-ND

J1 1x2 Header 2.54mm WM18785-ND

J2 2x5 Header 2.54mm 437-8021001010002101 Mouser

PCB Custom Board JHB00005 Jim Burney

Sockets for board

PLCC44 AE10057-ND

**DIP-24 Pin 575-1104732441001000 Mouser

**DIP-14 Pin (2 needed) 575-1104731441001000 Mouser

**DIP-8 Pin 575-1104730841001000 Mouser

**Adhesive feet (4 needed) RM822-ND

**Optional parts.

All parts are from Digi-key unless otherwise noted.

NOTE: The Til311 can be found on eBay also, the DIS1417 may be able to replace the Til311.

Always drive the Decimal Point of the display with and Open Drain buffer. If you don’t, the DP may not turn off completely, depending on the voltage supplied. The supply voltage should be from 6.5 Volts to 12 Volts, and current should be limited to about 160mA. If using a power supply, please current limit. The regulators will get very HOT, so it is better to operate on the lowest voltage possible. At 9V input, power dissipation is 3/4Watts in the 5V regulators.

CPLD development board - Two Digit counter - Jim Burney – May 27, 2018


Parts placement for the CPLD development board Two Digit counter

WARNING

This is not a how to guide, this assumes you know how to use Quartus 13, so no step by steps will be given, just an over view or highlights will be shown. It is up to you to get the information you need from reading the course book and doing the labs.

CPLD development board - Two Digit counter - Jim Burney – May 27, 2018

The switches that drive the CPLD are active low, this means when the switch is in the ON position, the output is Low, and when the switch is in the OFF position, the output is High.

This is also known as negative logic or shown by drawing a line (bar) over the signals name.

In this paper, it will be referred to as negative logic.

Positive logic means just the opposite, when the switch is on, the output is high, and when off, the output is low, this is also called active high logic.

To change from one type of logic to the other, you must invert the signal, it is that easy.

So, the first step in testing the CPLD development board you just made is to test some of the switches and the displays. This will also show you how the displays work and hopefully reinforce the concept of positive and negative logic.

For this test you are going to use switches 1,2,3,4,9,10, and 12 only, and both displays, and their decimal points will be tested. The switches will be inverted to make them the same logic levels that the displays work on, positive logic. Again, this is done by simply inverting the switch inputs, now when the switches are on, they will have a high output or be active high state.


This makes it easier to understand how these hexadecimal displays work.

First if you turn all switches off, the displays show 00 on the displays, but as soon as you turn switch 12 on, the displays BLANK and no numbers are shown. This shows that the blank signal to the display is now active high, meaning the displays blank when high.

The data buss is straight forward, but the bits of the buss go to both displays, so the Latch signal is used to hold the data on each one of the displays. These Latch signals are used to de-multiplex the data buss, so each display gets the information meant for it.

So, with all switches in the off position, turn on switch 1, and note that two 8’s are shown.

Now turn on switch 9 and note that the displays still show 88. Now turn on switch 2, the right display should be showing C and the left display should be 8, so 8C should now be shown on the displays. The reason this happened is that the data was LATCHED for the left display by turning switch 9 ON. This made Latch HIGH, and Latch is an active High signal, latch means to hold something, in this case it’s data. To help drive this point home, with 8C still on the displays, turn switch 10 on, then change switch 1 and 2 off. The displays should still read 8C, now turn switch 9 and then switch 10 off, as you did this the right, then the left display should have been replaced with Zeros (00).

CPLD development board - Two Digit Ccounter - Jim Burney – May 27, 2018

As both displays use the same lines to get their data from, the latch signals are used to let the displays get their information from the same lines, but at different times. This is called

Multiplexing, and is using the same lines to convey different information at different times. This is used to reduce the number of wires needed to carry information, and de-multiplexing is used to convert it back. More on this later, but just know, the world of electronics lives by multiplexing.

This is not to be confused with encoding and decoding, as that is used to change one type of information in to another, like decimal to binary, and binary to decimal.

So, let’s look at making the decimal points of the displays flash. This CPLD is clocked by an evil 66.6Khz signal form a 555 timer IC. So many of you used this timer to make blinking LED project in your first quarter here, but your timer was set very low frequency, so you could see the LED blink. However, this timer is will beyond your visual perception and will have to be slowed down to be seen, and this is done with dividers in the digital world.

This 66.6KHz signal from the timer is called a clock, and this is going to drive pin 24 of the CPLD, then a divider chain made up of four divide by 16 counter. This will make the clock signal about 1Hz or 1 pulse per second, this is well within your visual range. In other words, the 66.6 KHz gets divided by 65,536, giving about a 1Hz signal, this in turn is connected to one of the displays DP, then the signal is inverted and drives the displays.

This test also let you know how to drive the displays, and that the clock source works. however, it did not test all the switches. This is addressed in the next section with a priority encoder to test the switches and display.

CPLD development board - Two Digit counter - Jim Burney – May 27, 2018

Your project should look like this now.


Close-up shot for clarity


Play with this until you really understand what is going on here, even change it.

A priority encoder takes the highest decimal numbered input and converts that to Binary Coded Decimal (BCD), regardless of any lower numbered inputs. This encoder is based on negative logic (active low, or NOT by a bar over the signal name, or in this case, by a small bubble on the input and outputs, this also means NOT, and not is a negative.

As the encoder is already negative logic, the switches going to the encoder don’t need to be inverted, as they are negative logic already. The output however needs to be inverted as the displays work on positive logic (active high). This project shows that all the switches are working, as well as the displays.

Switches 10,11, and 12 do need to be inverted, as they drive the displays directly, so now the whole thing is based on positive logic. Note there are times you want to mix the two logic types, but this is not one of them.


CPLD development board - Two Digit counter - Jim Burney – May 27, 2018

Again, the counter chain is used to toggle the DP of the displays and show that the 555 timer is working at the right frequency and clocking the CPLD. This is the same divider chain used before, just draw differently.


Again, play with the latching and blanking, get a feel for it.

CPLD development board - Two Digit counter - Jim Burney – May 27, 2018

This last one is a few counters that you have seen before and a multiplexer driving the two displays and more blinking decimal points, the first four counters are just the same as before, but again they have been drawn a little differently. This is to show you that the same thing can be drawn in different ways. You must learn how to see what is really going on, as things may be drawn to save space.


This will count-up in hexadecimal from 0x00 to 0xFF at a fast rate, you will need to figure out the pin assignments and how this multiplexes the displays, if you want to make the two-digit calculator. Everything you need to know is here for multiplexing the displays, you just must understand what is going on. Hint, don’t worry about how the counters work, just look at how the data from the counters is selected in time with the displays.

CPLD development board - Two Digit counter - Jim Burney – May 27, 2018

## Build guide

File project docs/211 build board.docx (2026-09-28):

Lake Washington Institute of Technology

Electronics 211

Chap 7

Board Build/testing

Full Adder / Subtraction

Calculator

Feb 20^t^h, 2017

James Burney

Electronics 211, Board Build – James Burney, Feb 20^t^h, 2017

Executive Summary – The goal of this lab was to build a development board for the 7000 series CLPD and conduct our labs on it. To this end a schematic was given with the rear view of the socket shown to make construction easier. However, not all information was given, so that the data sheet would need to be used and some thought would be needed to finalize the design. I did a pre-lay out of a board design in my head, then did the pin mapping, and constructed a hand wired board. I used this board to conduct chap4 and do chap 7. In this report, I will discuss all projects done with this board and how I did them, and what was learned. So, in the end, the goals of this lab were completed by following the fine directions of our instructor, Professor Peter Welty.

Parts used

7000ae CLPD

FDN 367 display

44 Pin PLCC Socket

10 10KOhm ¼W 5%

8 270 Ohm ¼W 5%

10 pos sw.

LM 1117 3.3

30Ga wire

Equipment used

HP 34401a

Windows 10 pc with usb blaster

I first had to draw a schematic of what I wanted to do with the pin assignment of the 7000 CLPD. I made changes to the pins assignments as I constructed the board to make it easier to build. In this part of the lab, I learned that note taking is a big part of the job. As without documenting how it was done, one would not have the info needed to program the part.


Electronics 211, Board Build – James Burney, Feb 20^t^h, 2017

After building the board, I wanted a simple way to test that all of the I/O of my layout, and test all parts of the board. To this end, I used a priority encoder to read the switch inputs from 1 to 9 and feed them into a 74147, the output was feed into a 7447 to convent the BCD to 7 segment display. The 10th switch was feed to the displays D.P. to show it operation. Some mods were made to the 74147 for negative logic levels in my design, this will be discussed later in the report.

Priority Encoder (10 to 4 Encoder) BCD Display Driver


Now on to chapter 7.

First the book wanted us to wire-up a full adder, I just pulled a 7483 from the library and added I/O to it as shown in the book.

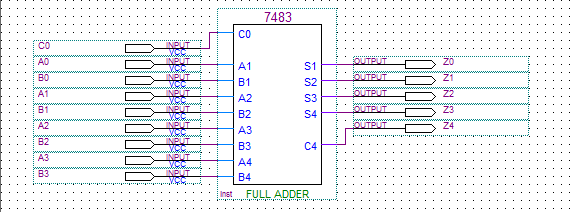
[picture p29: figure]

Next the book wanted a Subtractor Module made by inverting the B inputs to the adder.

Not sure of the point of this, as it is not used.

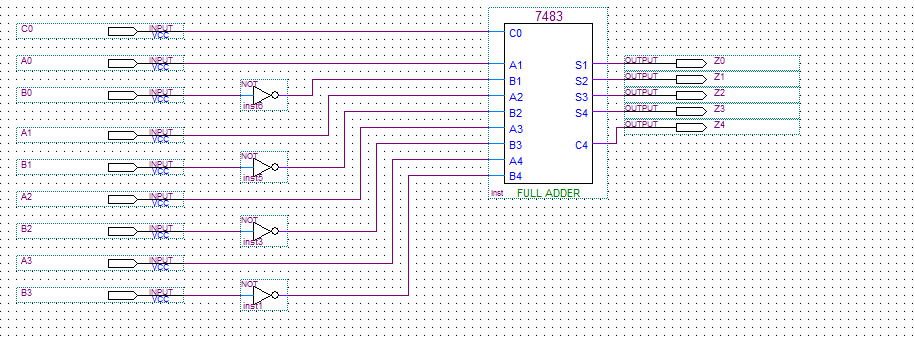
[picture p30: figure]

Electronics 211, Board Build – James Burney, Feb 20^t^h, 2017

Next up as to make the add/sub module from the full-adder. And just to be a brainless zombie, I followed the book poor layout directly.

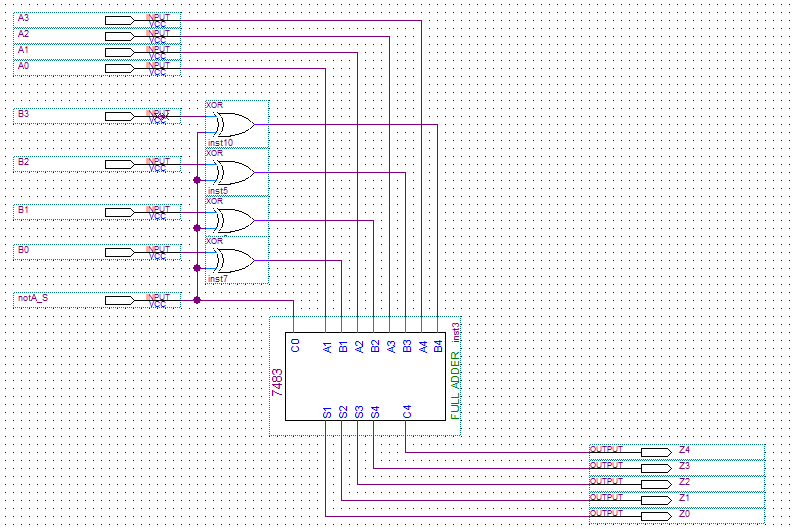
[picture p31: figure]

Next up is to use the full-adder for the multiplication unit. There’s a lot to this little guy.

In this picture, there was a short on the bottom and gate, this was fixed.

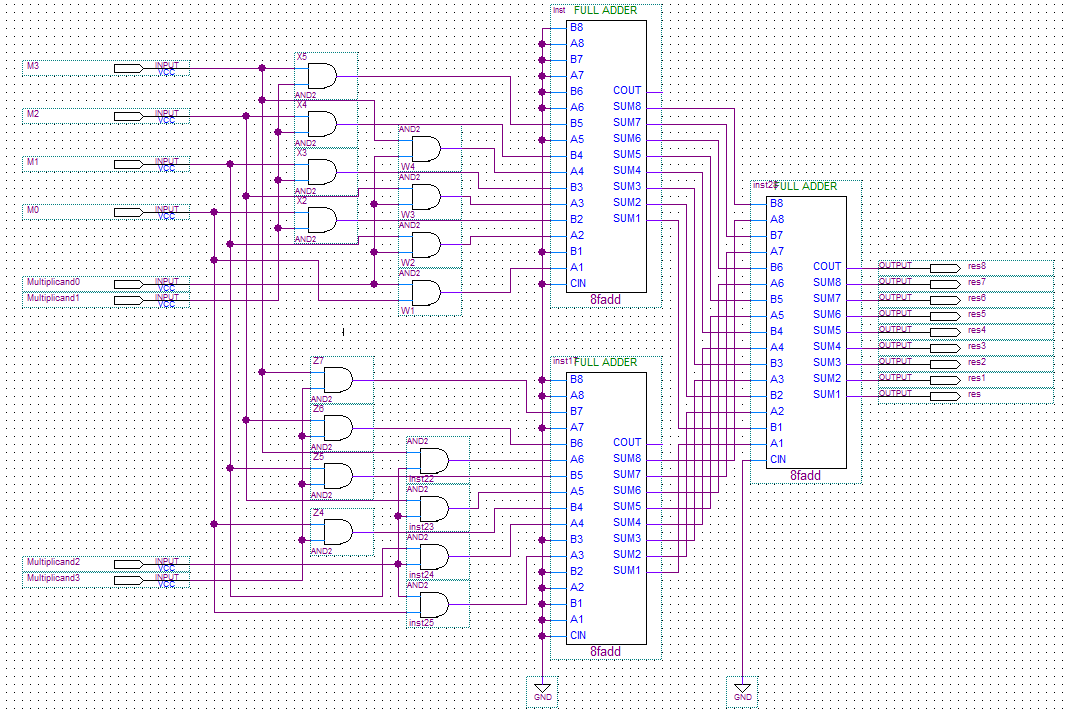
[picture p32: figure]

Electronics 211, Board Build – James Burney, Feb 20^t^h, 2017

Next up, the Min Max module.

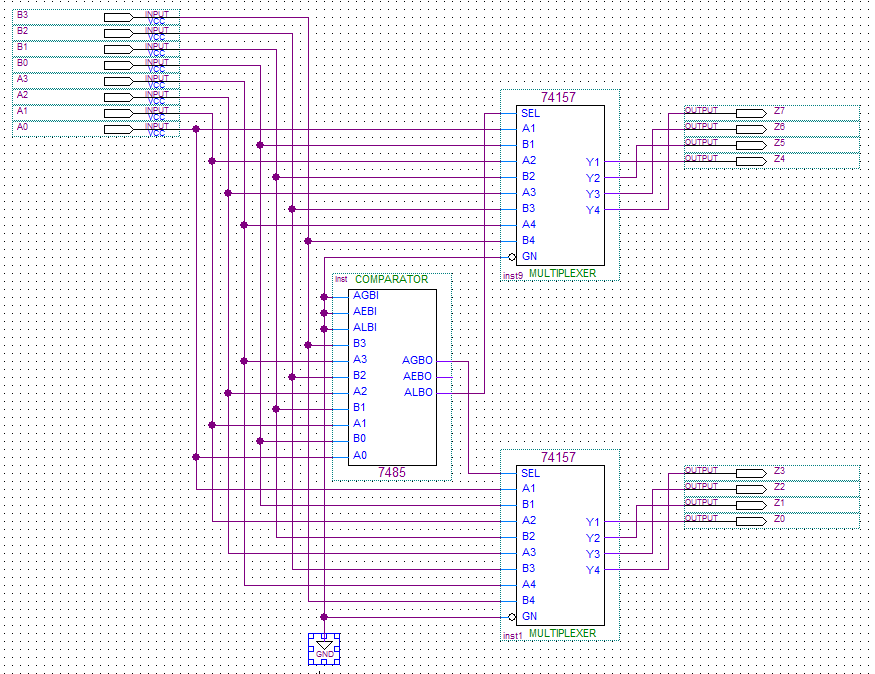
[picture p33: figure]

And then the tristate buffers, just away to select one of three outputs from the calculator.

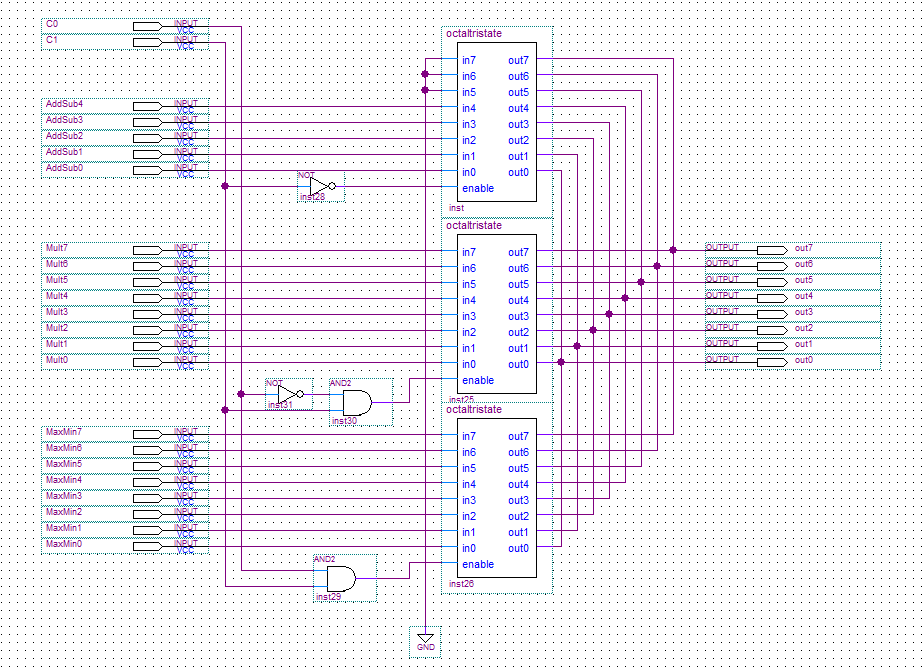
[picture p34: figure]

Electronics 211, Board Build – James Burney, Feb 20^t^h, 2017

Next, is the calculator.

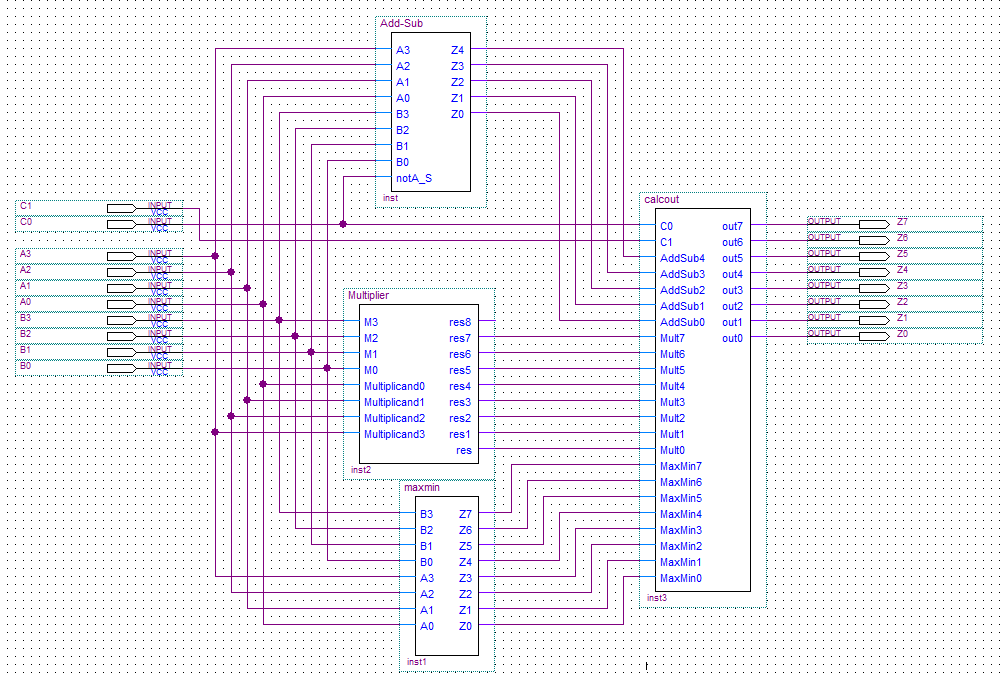
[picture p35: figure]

Next is to add a multiplexer and the Hex display.

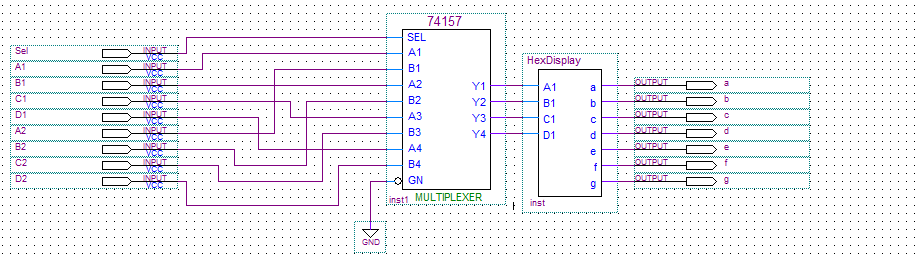
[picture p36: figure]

End result of combining all sub-logic into the design.

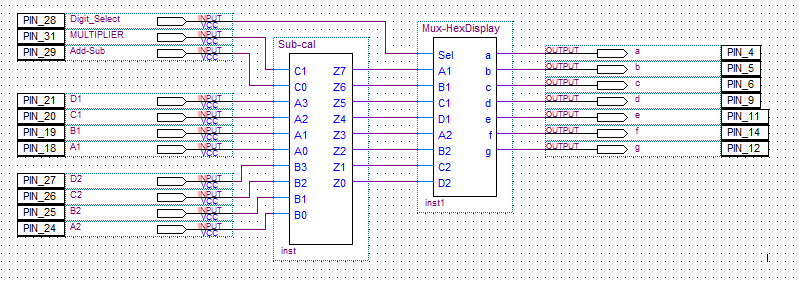
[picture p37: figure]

Electronics 211, Board Build – James Burney, Feb 20^t^h, 2017

Good compile on larger chip. However, my board will need another switch added, and that will be really hard to pull off.

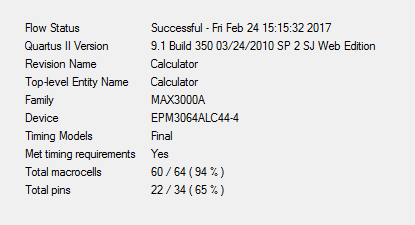
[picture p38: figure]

My hex display.

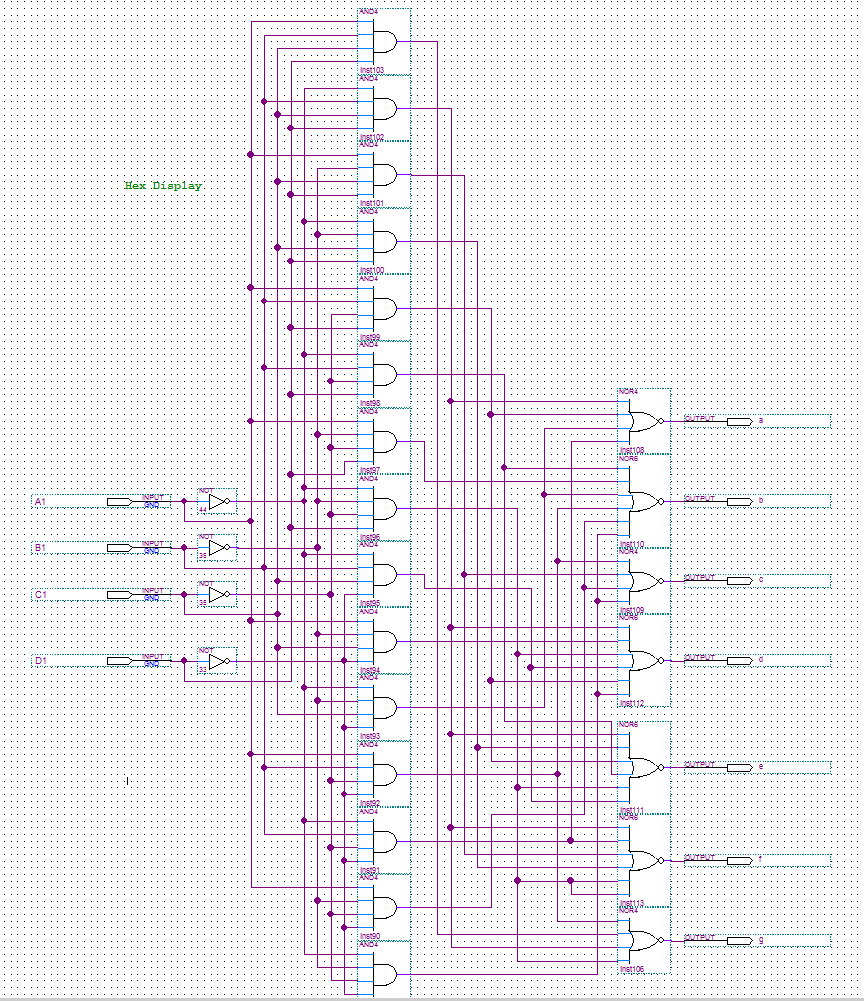
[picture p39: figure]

Electronics 211, Board Build – James Burney, Feb 20^t^h, 2017

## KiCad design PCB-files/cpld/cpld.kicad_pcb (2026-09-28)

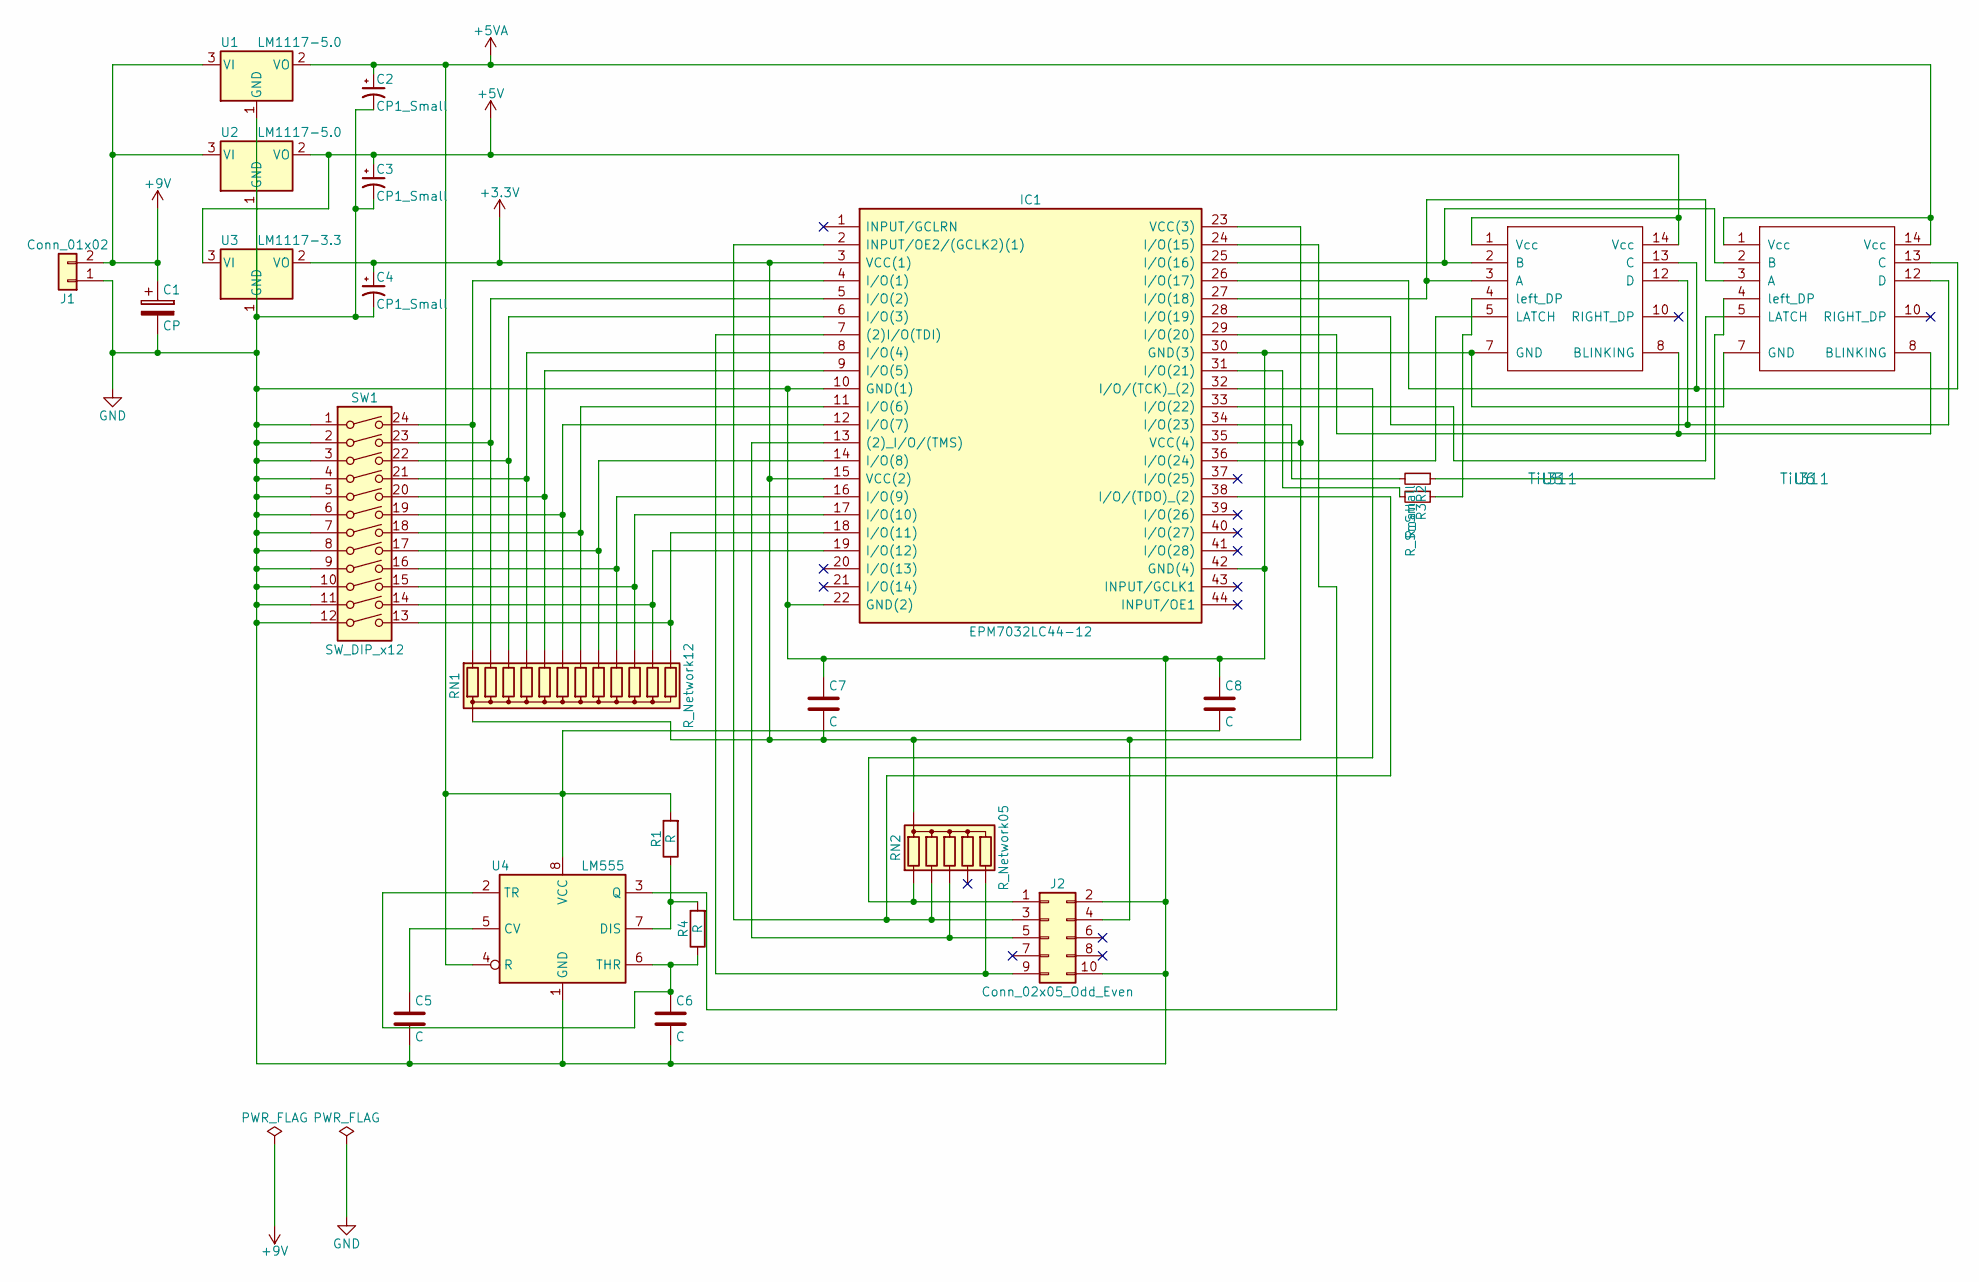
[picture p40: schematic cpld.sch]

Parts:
C1: CP; CP_Radial_D5.0mm_P2.50mm
C2, C3, C4: CP1_Small; CP_Radial_D5.0mm_P2.50mm
C5, C6, C7, C8: C; C_Axial_L3.8mm_D2.6mm_P7.50mm_Horizontal
IC1: EPM7032LC44-12; PLCC44; Manufacturer_Part_Number EPM7032LC44-12
J1: Conn_01x02; Pin_Header_Straight_1x02_Pitch2.54mm
J2: Conn_02x05_Odd_Even; Pin_Header_Straight_2x05_Pitch2.54mm
R1, R4: R; R_Axial_DIN0204_L3.6mm_D1.6mm_P7.62mm_Horizontal
R2, R3: R_Small; R_Axial_DIN0204_L3.6mm_D1.6mm_P7.62mm_Horizontal
RN1: R_Network12; Socket_Strip_Straight_1x13_Pitch2.54mm
RN2: R_Network05; Socket_Strip_Straight_1x06_Pitch2.54mm
SW1: SW_DIP_x12; SW_DIP_x12_W7.62mm_Slide
U1, U2: LM1117-5.0; TO-220
U3: LM1117-3.3; TO-220
U4: LM555; DIP-8_W7.62mm
U5, U6: Til311; DIP-14_W7.62mm

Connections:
+3V3: C4.1, C7.2, IC1.3 (VCC(1)), IC1.15 (VCC(2)), IC1.23 (VCC(3)), IC1.35 (VCC(4)), J2.4, RN1.1 (common), RN2.1 (common), U3.2 (VO)
+5V: C3.1, U2.2 (VO), U3.3 (VI), U5.1 (Vcc), U5.14 (Vcc)
+5VA: C2.1, C8.2, R1.2, U1.2 (VO), U4.4 (R), U4.8 (VCC), U6.1 (Vcc), U6.14 (Vcc)
+9V: C1.1, J1.2, U1.3 (VI), U2.3 (VI)
GND: C1.2, C2.2, C3.2, C4.2, C5.2, C6.2, C7.1, C8.1, IC1.10 (GND(1)), IC1.22 (GND(2)), IC1.30 (GND(3)), IC1.42 (GND(4)), J1.1, J2.2, J2.10, SW1.1, SW1.2, SW1.3, SW1.4, SW1.5, SW1.6, SW1.7, SW1.8, SW1.9, SW1.10, SW1.11, SW1.12, U1.1 (GND), U2.1 (GND), U3.1 (GND), U4.1 (GND), U5.7 (GND), U6.7 (GND)
unnamed: C5.1, U4.5 (CV)
unnamed: C6.1, R4.1, U4.2 (TR), U4.6 (THR)
unnamed: IC1.2 (INPUT/OE2/(GCLK2)(1)), IC1.38 (I/O/(TDO)_(2)), J2.3, RN2.3 (R2)
unnamed: IC1.4 (I/O(1)), RN1.2 (R1), SW1.24
unnamed: IC1.5 (I/O(2)), RN1.3 (R2), SW1.23
unnamed: IC1.6 (I/O(3)), RN1.4 (R3), SW1.22
unnamed: IC1.7 ((2)I/O(TDI)), J2.9, RN2.6 (R5)
unnamed: IC1.8 (I/O(4)), RN1.5 (R4), SW1.21
unnamed: IC1.9 (I/O(5)), RN1.6 (R5), SW1.20
unnamed: IC1.11 (I/O(6)), RN1.8 (R7), SW1.18
unnamed: IC1.12 (I/O(7)), RN1.7 (R6), SW1.19
unnamed: IC1.13 ((2)_I/O/(TMS)), J2.5, RN2.4 (R3)
unnamed: IC1.14 (I/O(8)), RN1.9 (R8), SW1.17
unnamed: IC1.16 (I/O(9)), RN1.10 (R9), SW1.16
unnamed: IC1.17 (I/O(10)), RN1.11 (R10), SW1.15
unnamed: IC1.18 (I/O(11)), RN1.13 (R12), SW1.13
unnamed: IC1.19 (I/O(12)), RN1.12 (R11), SW1.14
unnamed: IC1.24 (I/O(15)), U4.3 (Q)
unnamed: IC1.25 (I/O(16)), U5.2 (B), U6.2 (B)
unnamed: IC1.26 (I/O(17)), U5.13 (C), U6.13 (C)
unnamed: IC1.27 (I/O(18)), U5.3 (A), U6.3 (A)
unnamed: IC1.28 (I/O(19)), U5.12 (D), U6.12 (D)
unnamed: IC1.29 (I/O(20)), U5.8 (BLINKING), U6.8 (BLINKING)
unnamed: IC1.31 (I/O(21)), R3.2
unnamed: IC1.32 (I/O/(TCK)_(2)), J2.1, RN2.2 (R1)
unnamed: IC1.33 (I/O(22)), U6.5 (LATCH)
unnamed: IC1.34 (I/O(23)), R2.2
unnamed: IC1.36 (I/O(24)), U5.5 (LATCH)
unnamed: R1.1, R4.2, U4.7 (DIS)
unnamed: R2.1, U6.4 (left_DP)
unnamed: R3.1, U5.4 (left_DP)

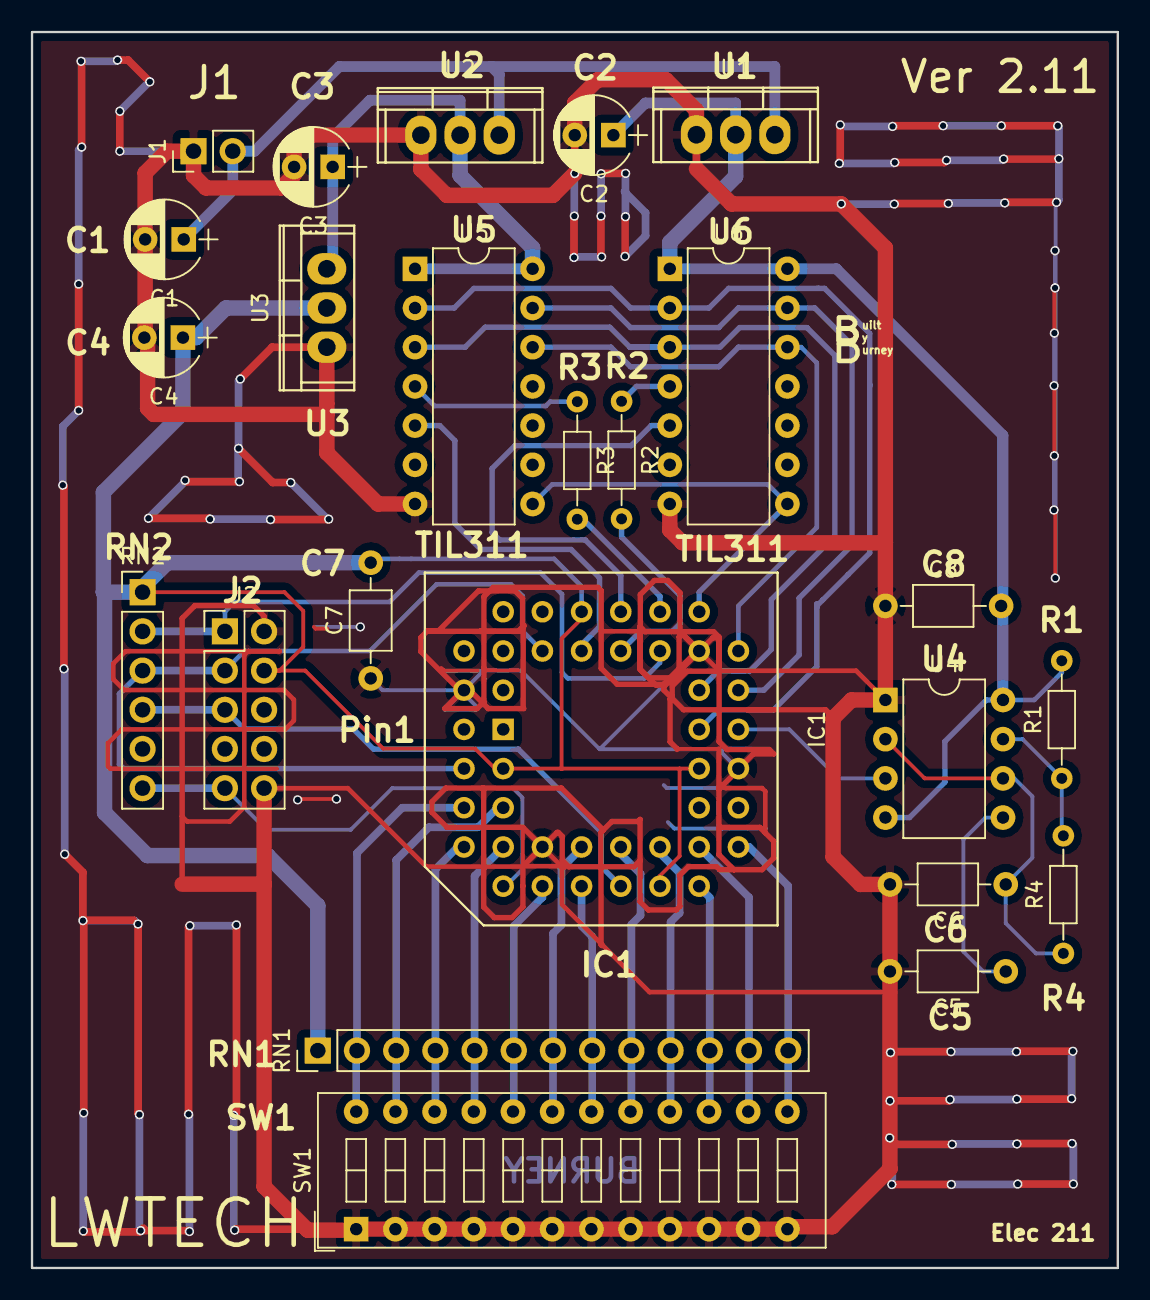
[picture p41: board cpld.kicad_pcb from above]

Board: 2 copper layers, 70.4 x 80.1 mm, 24 parts (0 on the bottom side), 36 nets.

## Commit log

2026-09-28 Initial commit: CPLD development system (PCB, gerbers, Quartus archive, docs, photos)
    [cpld-B.Cu.gbr, cpld-B.Mask.gbr, cpld-Edge.Cuts.gbr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]
2026-09-28 README: show PCB and schematic images under KiCad / fabrication
2026-10-16 Add board bring-up Quartus labs (board test, board-test-2, boardtest3).
2026-10-16 Add README status, license, device, and lab badges.
2026-10-16 Document MAX 7000S 5V vs 7000AE 3.3V; note white board photo setup.
2026-10-16 Replace single Calculator with Calculator-full-5v and Calculator-full-3v3.
